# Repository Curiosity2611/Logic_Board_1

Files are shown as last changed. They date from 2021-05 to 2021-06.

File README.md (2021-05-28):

## Full Documentation

I will amend this documentation as the project progresses.

**Logic Board 1 Variants:**

- Logic Board 1A (No wireless)
	- LB1A_DCA7M4_R512MB_F4GB (Dual Core A7 + M4, 512MB DDR3L RAM, 4GB eMMC)
	- LB1A_SCA7M4_R512MB_F4GB (Single Core A7 + M4, 512MB DDR3L RAM, 4GB eMMC)
- Logic Board 1B (Only BLE 5.0)
	- LB1B_DCA7M4_R512MB_F4GB (Dual Core A7 + M4, 512MB DDR3L RAM, 4GB eMMC)
	- LB1B_SCA7M4_R512MB_F4GB (Single Core A7 + M4, 512MB DDR3L RAM, 4GB eMMC)
- Logic Board 1C (Only WiFi)
	- LB1B_DCA7M4_R512MB_F4GB (Dual Core A7 + M4, 512MB DDR3L RAM, 4GB eMMC)
	- LB1B_SCA7M4_R512MB_F4GB (Single Core A7 + M4, 512MB DDR3L RAM, 4GB eMMC)
- Logic Board 1D (WiFi + BLE 5.0)
	- LB1B_DCA7M4_R512MB_F4GB (Dual Core A7 + M4, 512MB DDR3L RAM, 4GB eMMC)
	- LB1B_SCA7M4_R512MB_F4GB (Single Core A7 + M4, 512MB DDR3L RAM, 4GB eMMC)

**Logic Board I/O:**

Common expansion Board for all Logic Board 1 Variants. 

## A little background about the project

How it all started.

### Problem

Recently I came accross the ST's line of Microprocessors and I felt it fascinating. I personally felt this is one of the best Microprocessor out there in the market as it is the combination of an MPU and an  MCU. This combination has many use cases and I felt I should try this out. So I bought STM32MP157C-DK2 development board and started experimenting! <br>

Previously I had little experience working on couple of popular linux dev boards like the BeagleBone Black
and the Raspberry Pi. They are both fantastic boards to work with and they both have good community support. But while working with them, I realised a few bunch of problems:

- **Raspberry Pi Compute Module 4 + IO Board**
    - CM4 is easy to use but not ideal for mass production.
    - No support for analog signals at hardware level.
    - Software PWM possible but not very precise.
    - Cannot support real time application or processing.
    - Not fully open-source and very minimum customization possible. <br>
<br>

- **BeagleBone Black**
    - Easy to use but user has to own build hardware for production.
    - PRUs make RT applications possible but super difficult to use.
    - Cannot support MIPI-DSI and HD graphics.
    - Programming PRUs is not an easy task.

### Solution

**Best of both worlds**

**Hello World STM32MP1 !!**

- Board design inspired from Raspberry Pi Compute Module 4 and CM4 IO board.
- Operating system derived from Beaglebone Black with implementation of Bonescript Library and Cloud9 IDE.
- Footprint compatible Single or dual Cortex-A7 Processors + dedicated Cortex-M4 core for real-time and low-power applications.
- Support for MIPI-DSI display for HMI applications.
- Fully open-source Hardware and Software.

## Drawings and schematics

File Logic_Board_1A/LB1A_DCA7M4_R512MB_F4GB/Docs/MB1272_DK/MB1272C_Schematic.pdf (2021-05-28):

Title: MB1272

Size:

Reference:
A4 | Sheet: | of

Revision:

Project: STM32MP15-DISCO

C 01 | MB1272
12-SEP-18

DK2

Date:

Variant:

Table of contents | Legend

New in Rev C : X6 OSC, 100nF->1uF on C147 to C161, C191/C192 added, X1 NDK reference, ANA0/1 -> ARD_A2/3

Text to be added to silkscreen.

Sheet 1: Project (this page)

Sheet 2: Top

# STM32MP15-DISCO

MB1272

Sheet 3: STM32 MPU I/Os

Sheet 4: Power MPU

Sheet 7: Audio

Sheet 9: HDMI

Sheet 6: USB Host Hub &TypeC DRP

Sheet 5: Power PMIC

Sheet 8: DSI LCD Connector

Warning text.

Sheet 10: GPIO & Arduino Connectors

Sheet 11: DDR3 16bits

U_MB1272-TOP
MB1272-TOP.SchDoc

# Open Platform License Agreement

The Open Platform License Agreement (“Agreement”) is a binding legal contract between you ("You")

and STMicroelectronics International N.V. (“ST”), a company incorporated under the laws of the

Netherlands acting for the purpose of this Agreement through its Swiss branch 39, Chemin du

Champ des Filles, 1228 Plan-les-Ouates, Geneva, Switzerland.

By using the enclosed reference designs, schematics, PC board layouts, and documentation, in hardcopy

or CAD tool file format (collectively, the “Reference Material”), You are agreeing to be bound by

the terms and conditions of this Agreement. Do not use the Reference Material until You have read

and agreed to this Agreement terms and conditions. The use of the Reference Material automatically

implies the acceptance of the Agreement terms and conditions.

The complete Open Platform License Agreement can be found on www.st.com/opla.

Sheet 10: Ethernet

Sheet 11: Peripherals

Sheet 10: WLAN Bluetooth

Sheet 11: Peripherals

Notes to generate the
board layout.

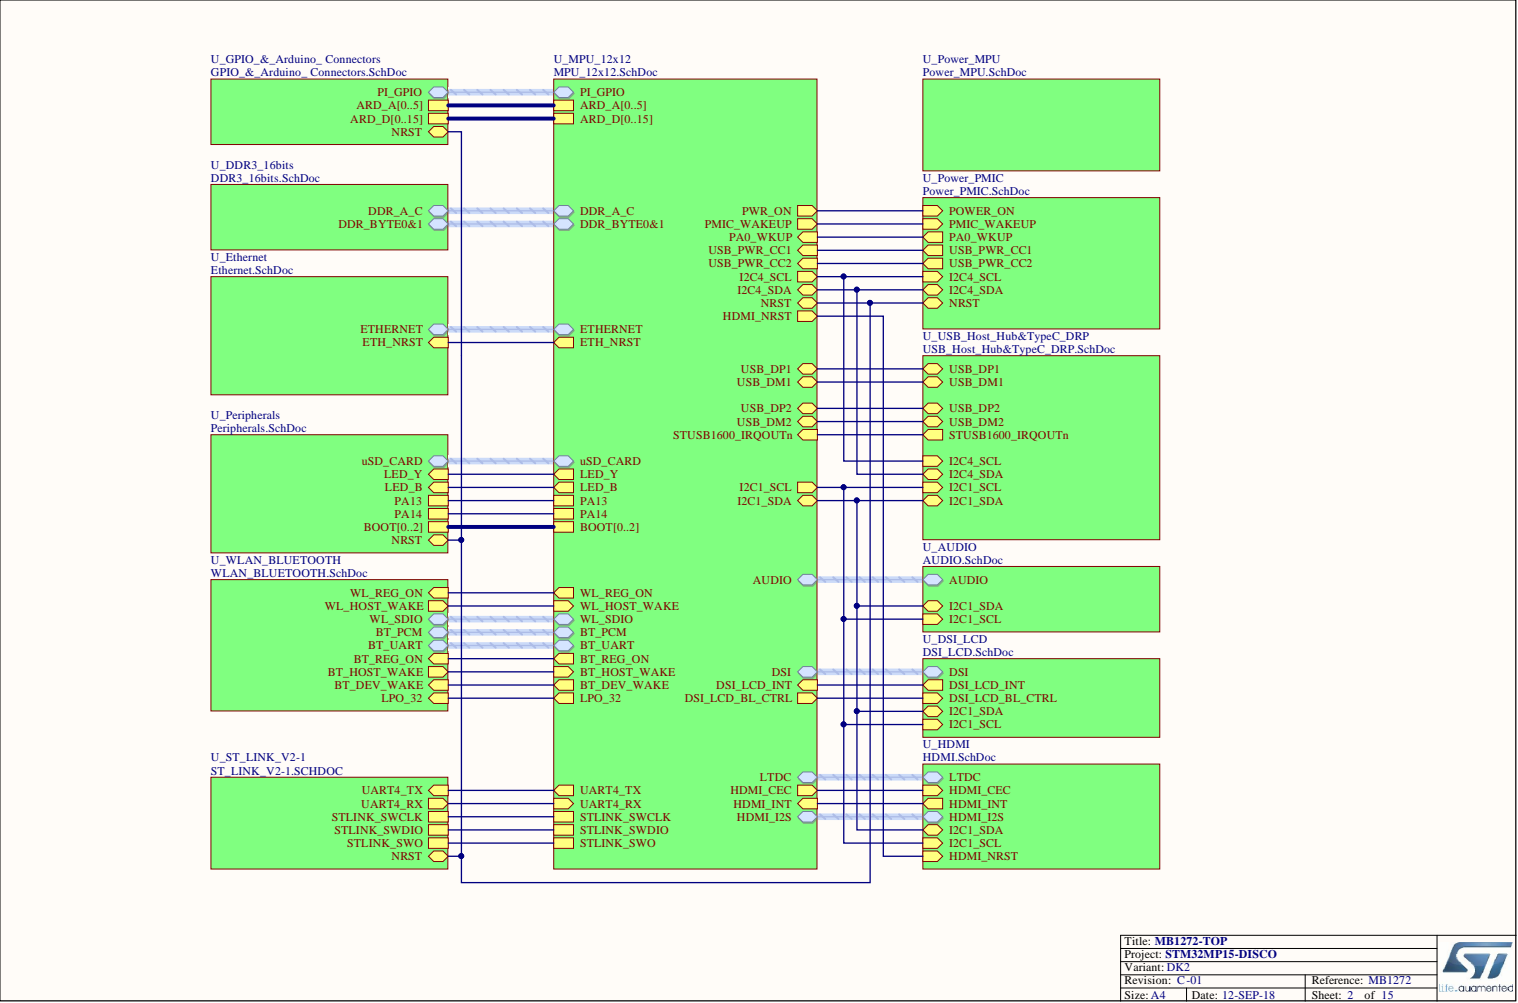
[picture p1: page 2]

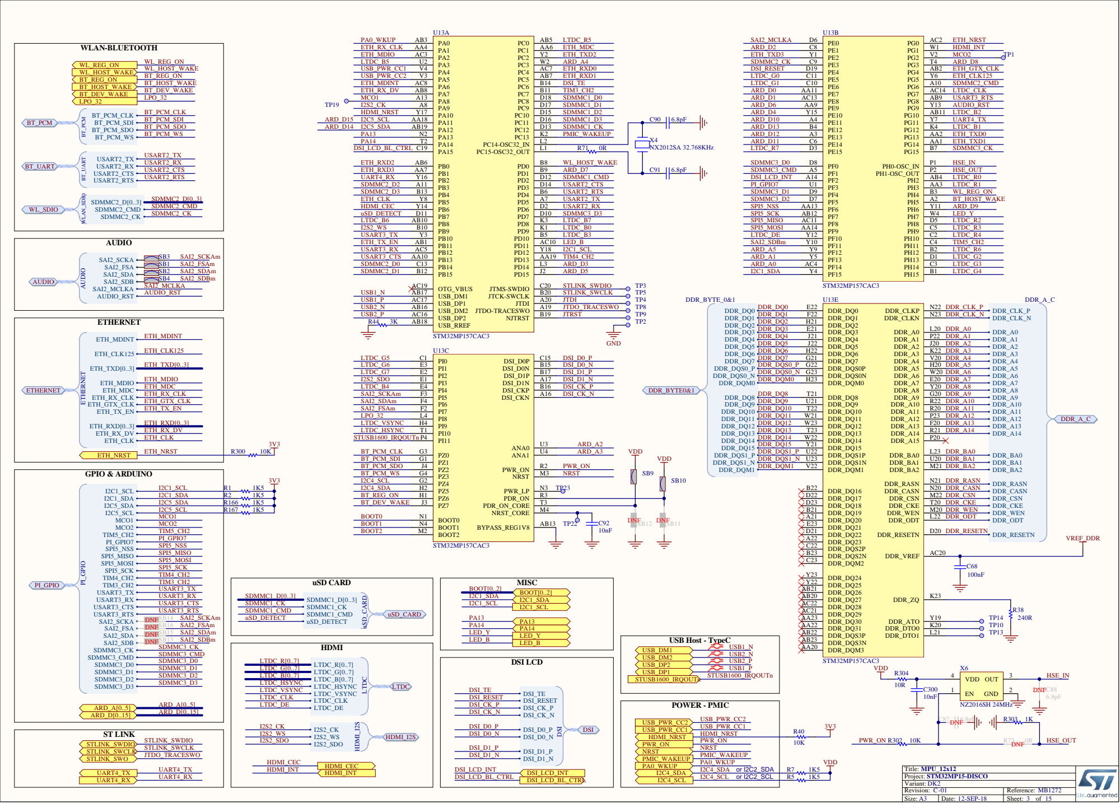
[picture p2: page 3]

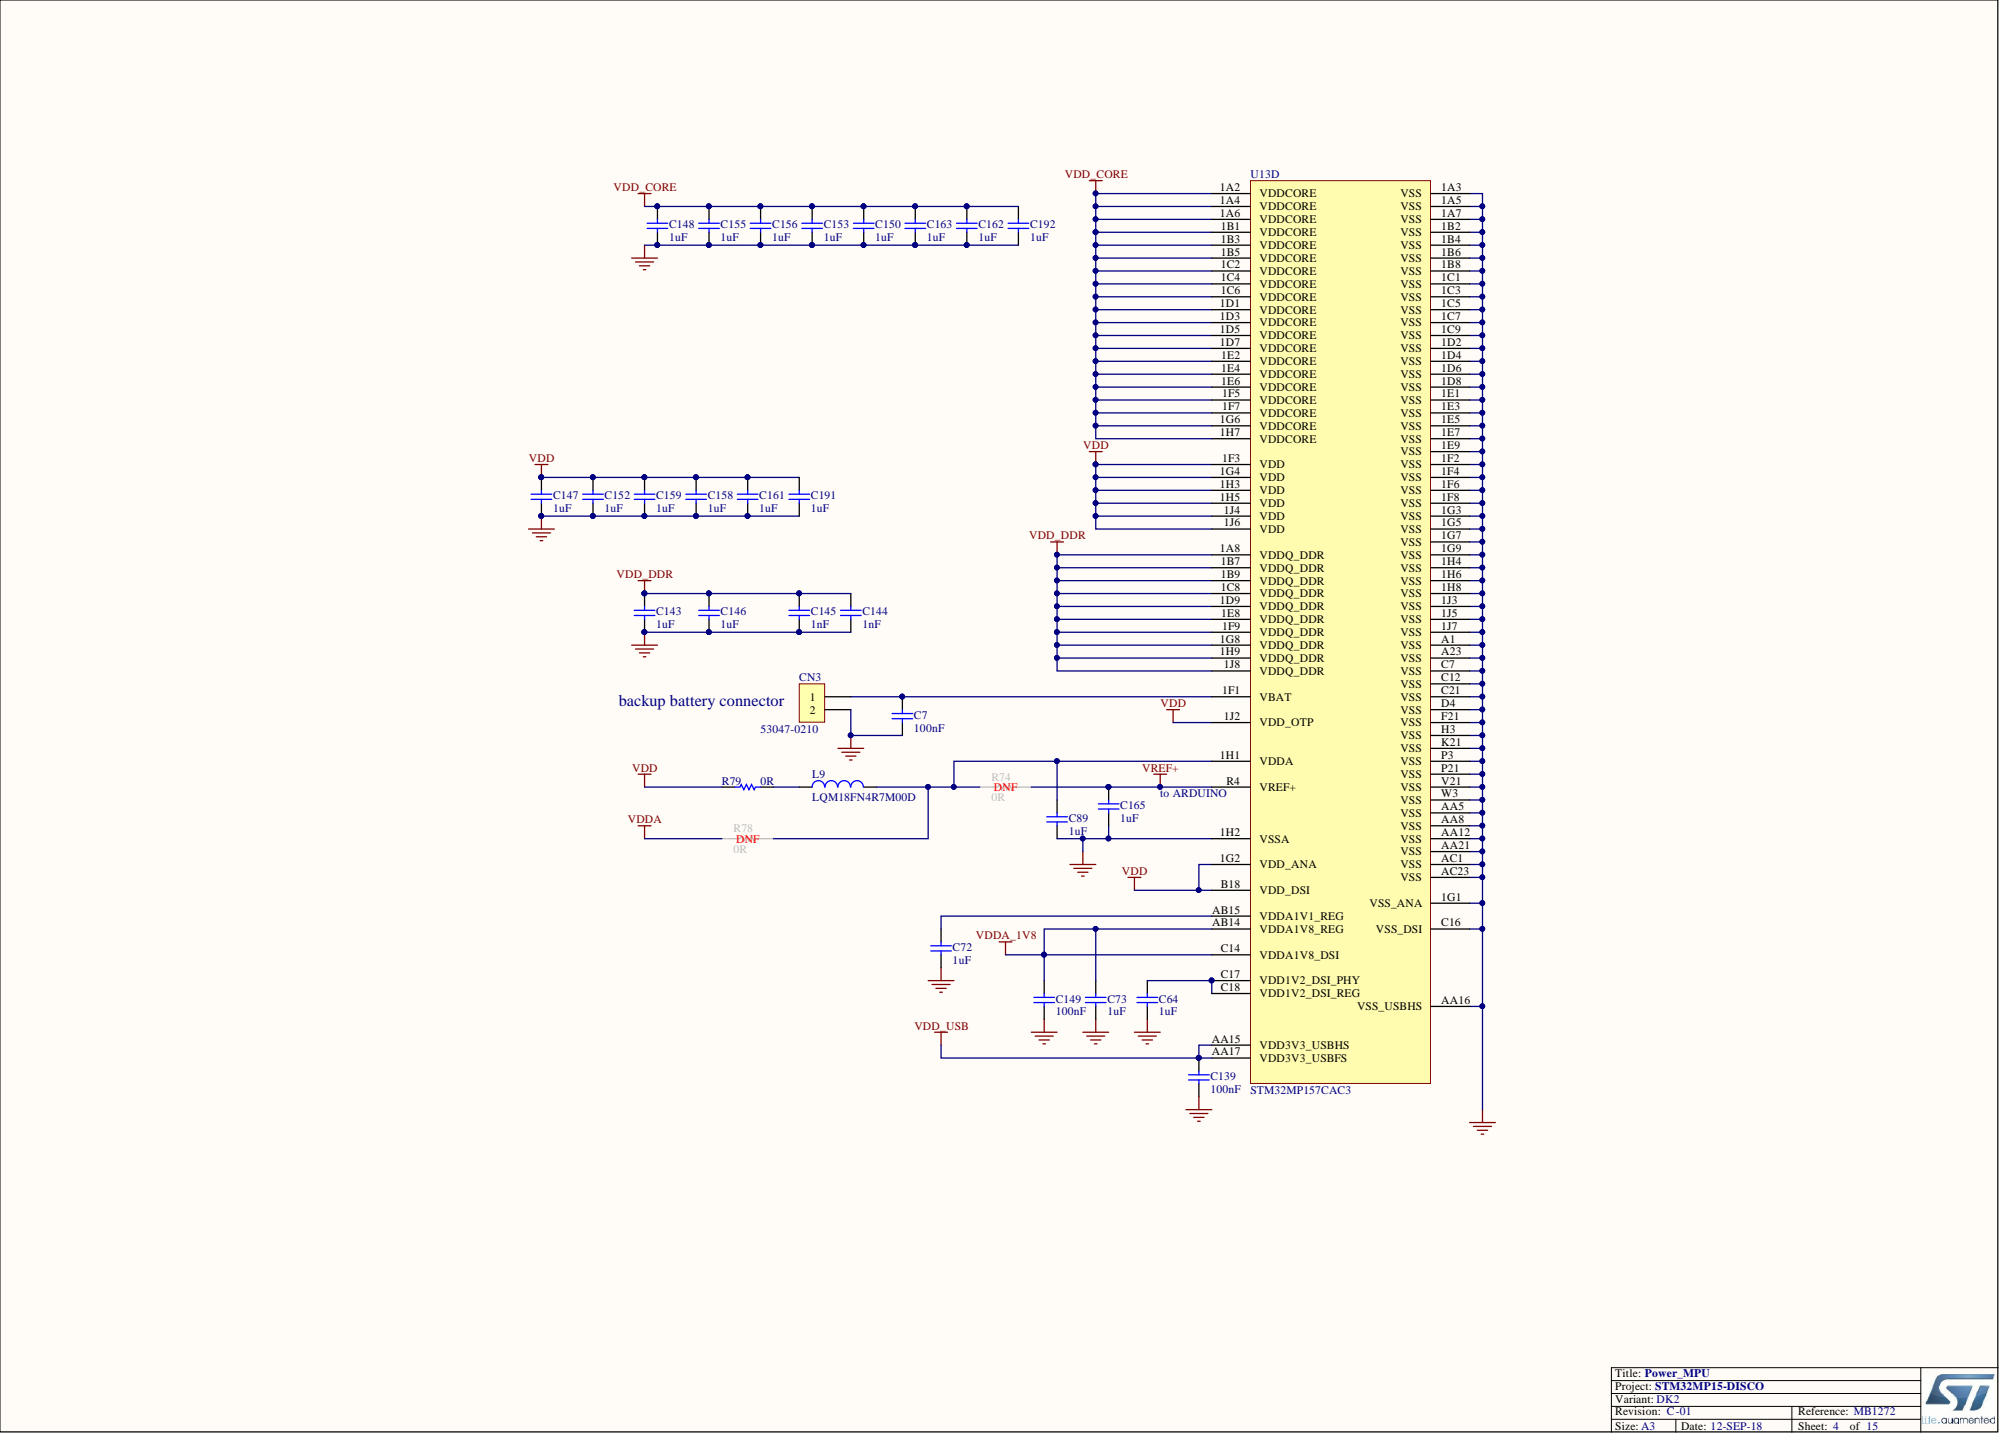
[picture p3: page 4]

R74 DNF | VREF+

VSSA 1H2

VDD_DSI B18

VDDA1V8_REG AB14 VDDA1V1_REG AB15

VDDA1V8_DSI C14

VDD1V2_DSI_PHY C17
VDD1V2_DSI_REG C18

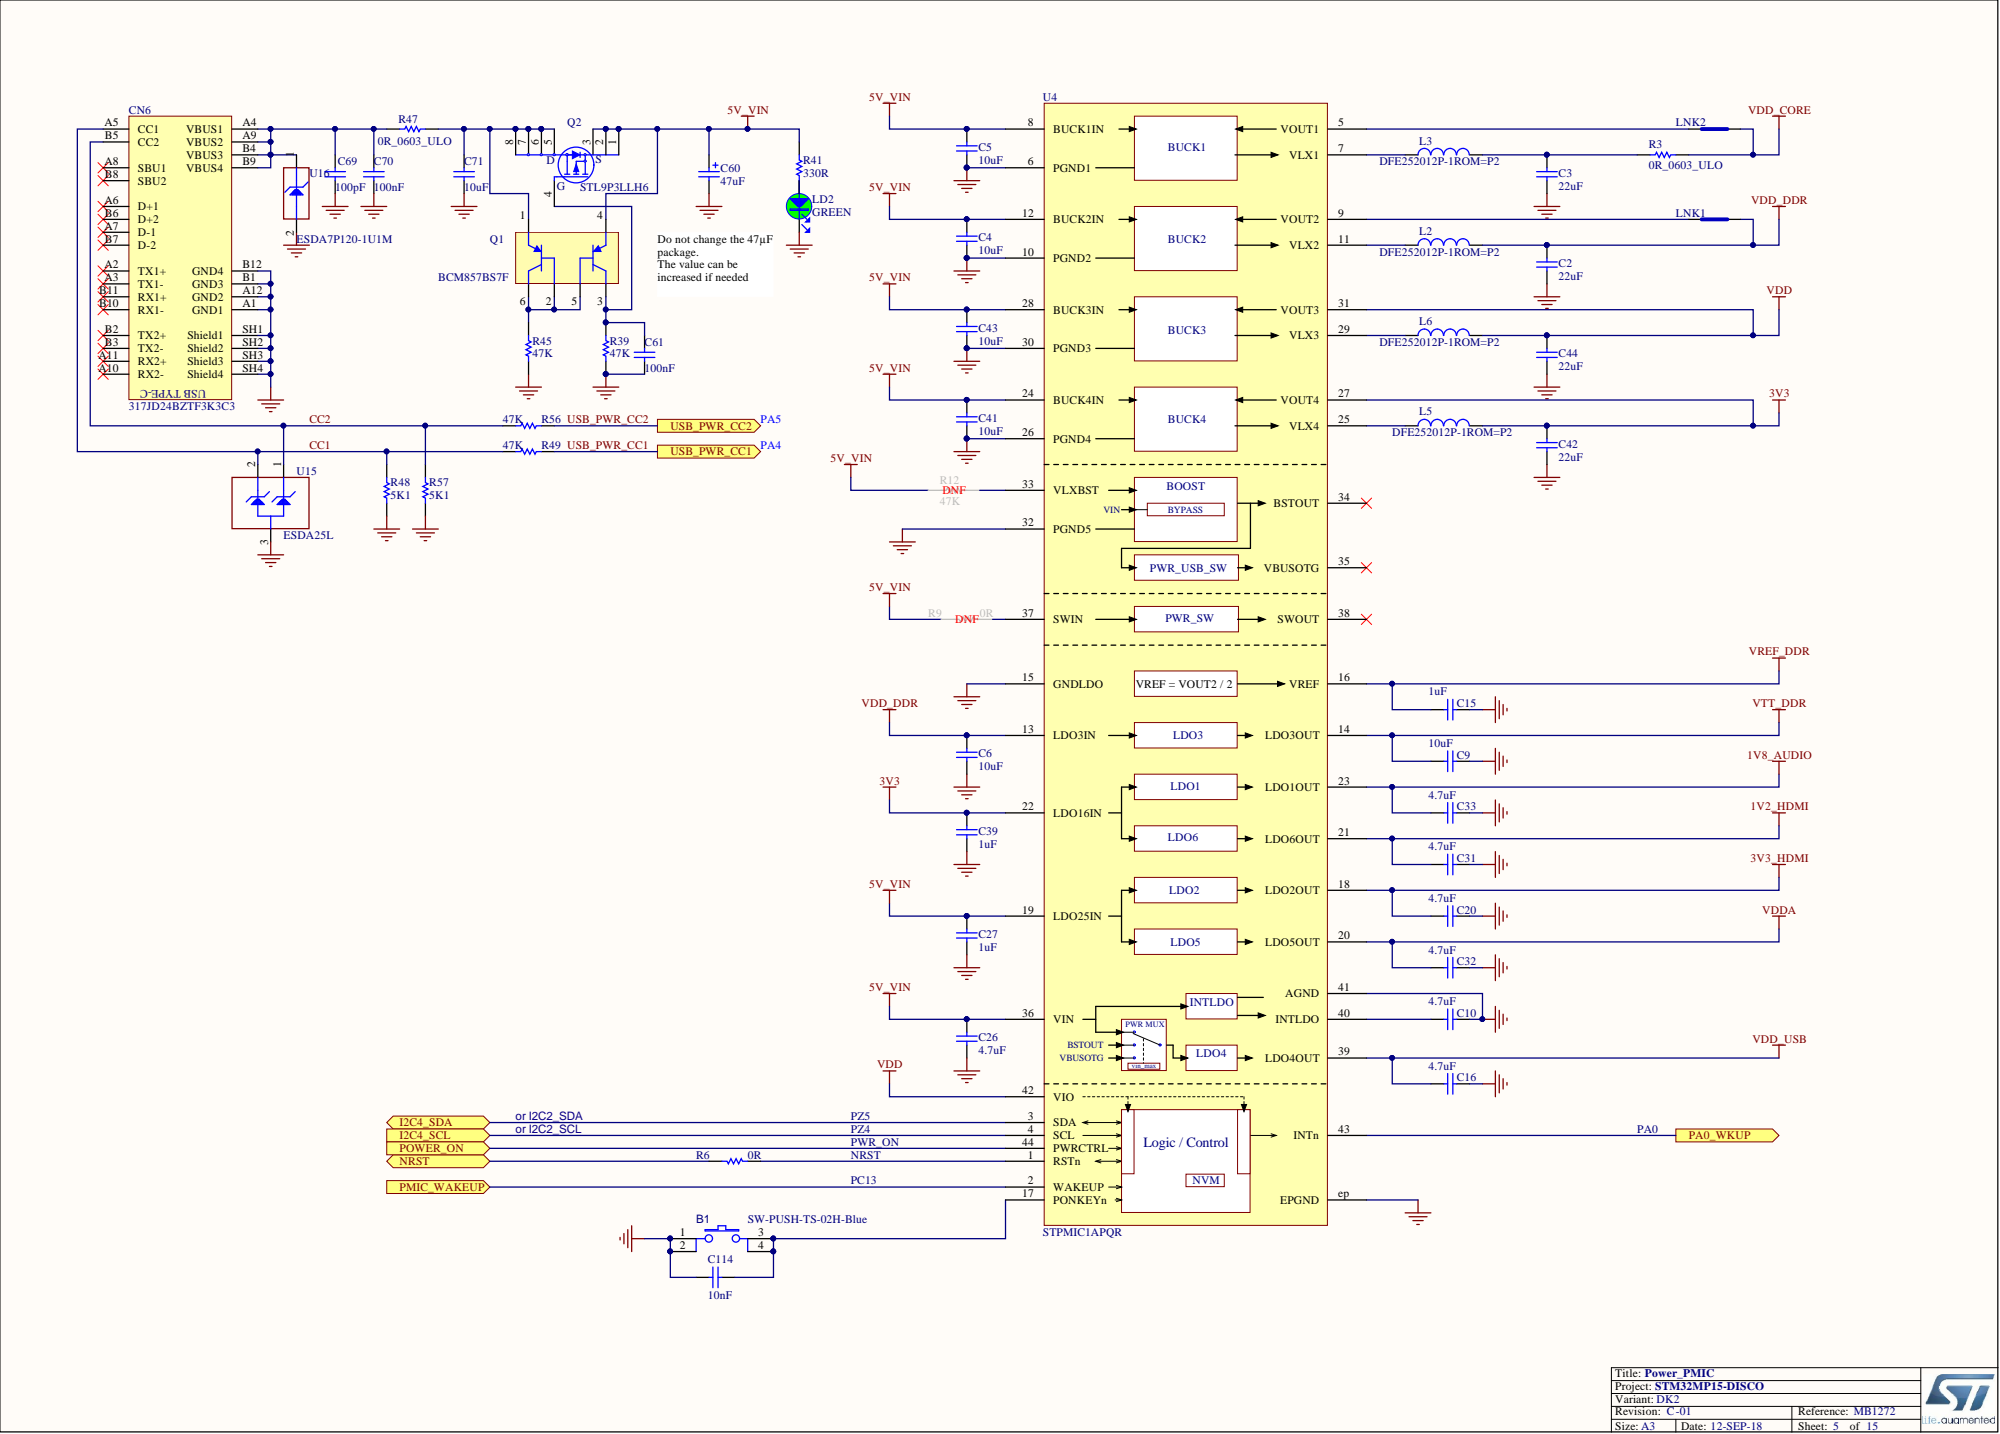
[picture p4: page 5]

package. The value can be increased if needed

PWR MU vin_max | X

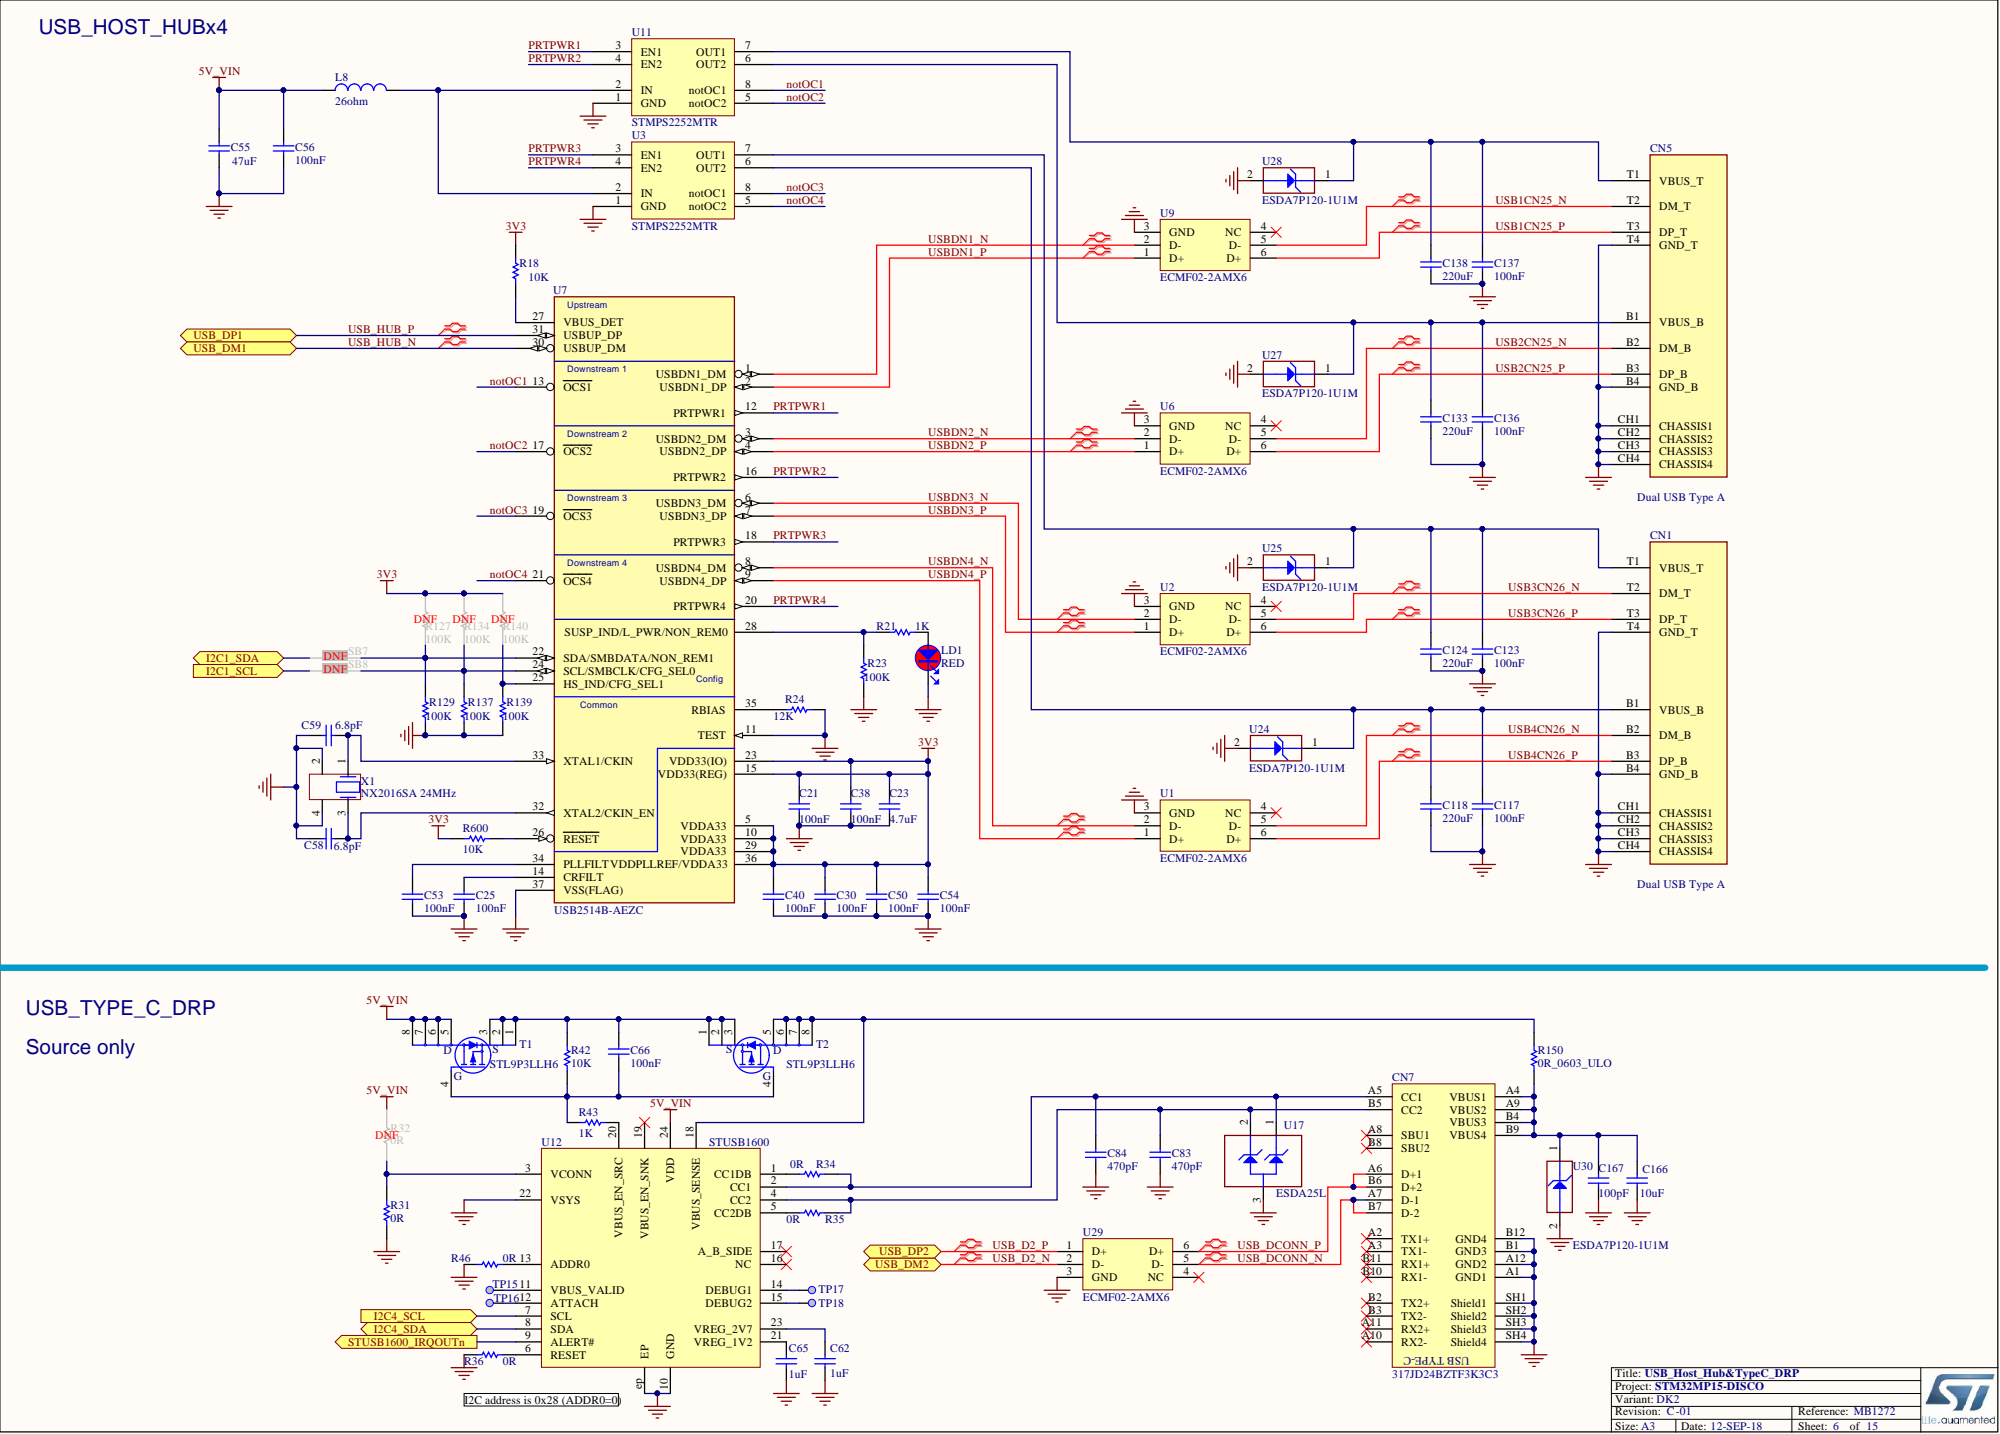
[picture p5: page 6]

USB1CN25_P | DP_T T3

GND_T T4

USB2CN25_P | DP_B B3

C133 | C136 | GND_B B4

CHASSIS4 CH4

CRFILT 14

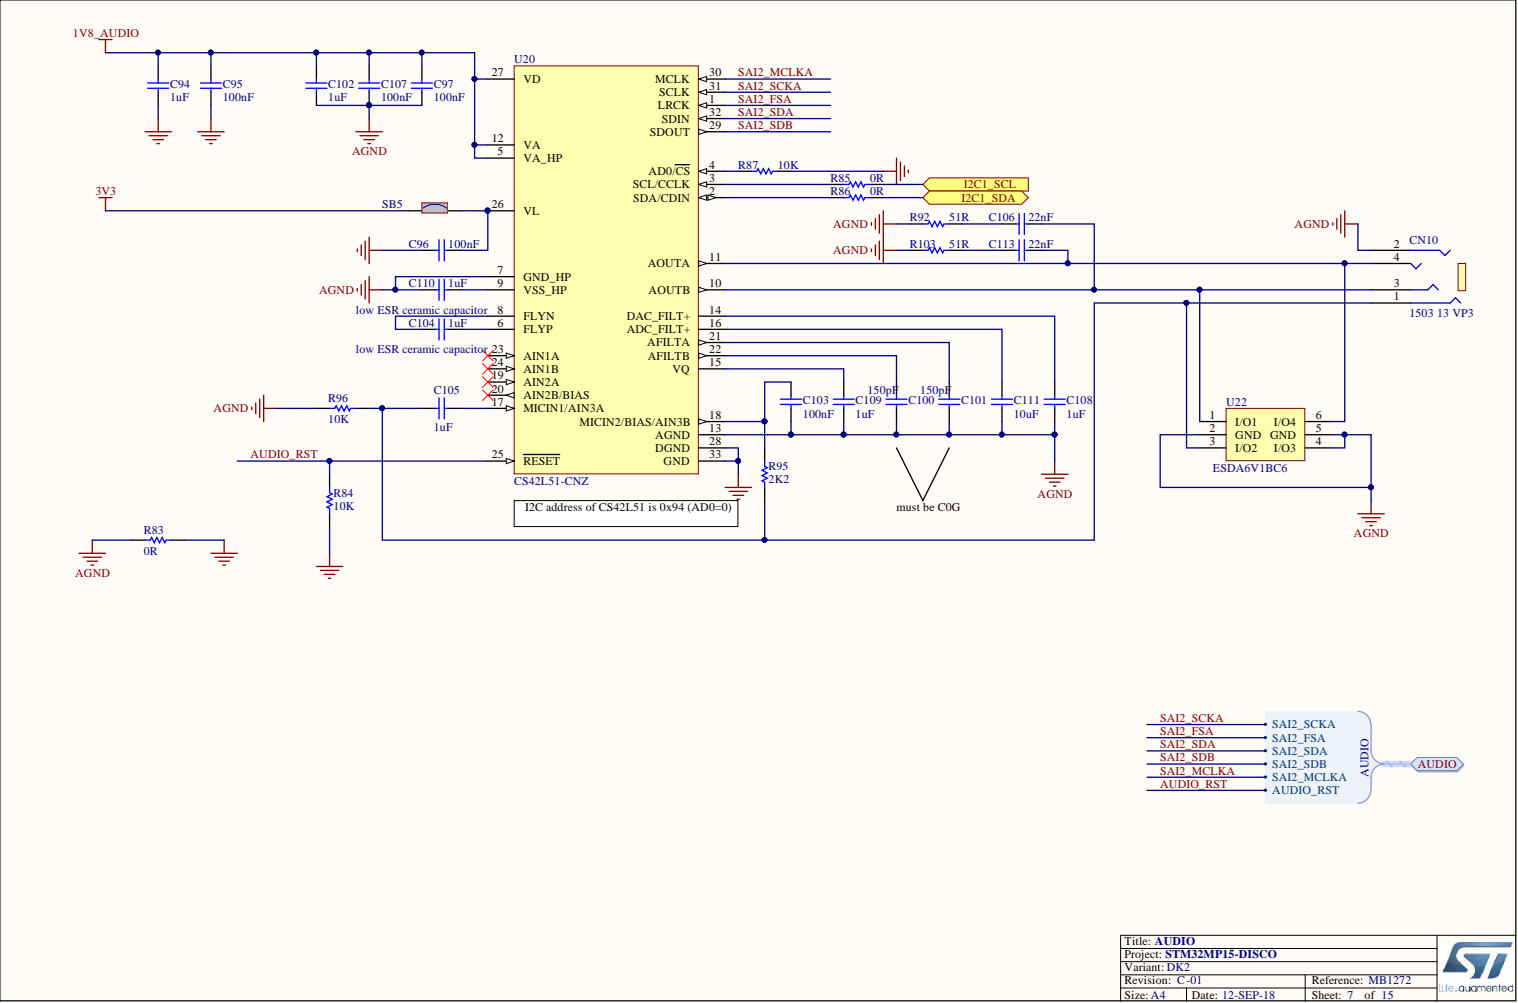
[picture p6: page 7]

GND_HP 7

low ESR ceramic capacitor

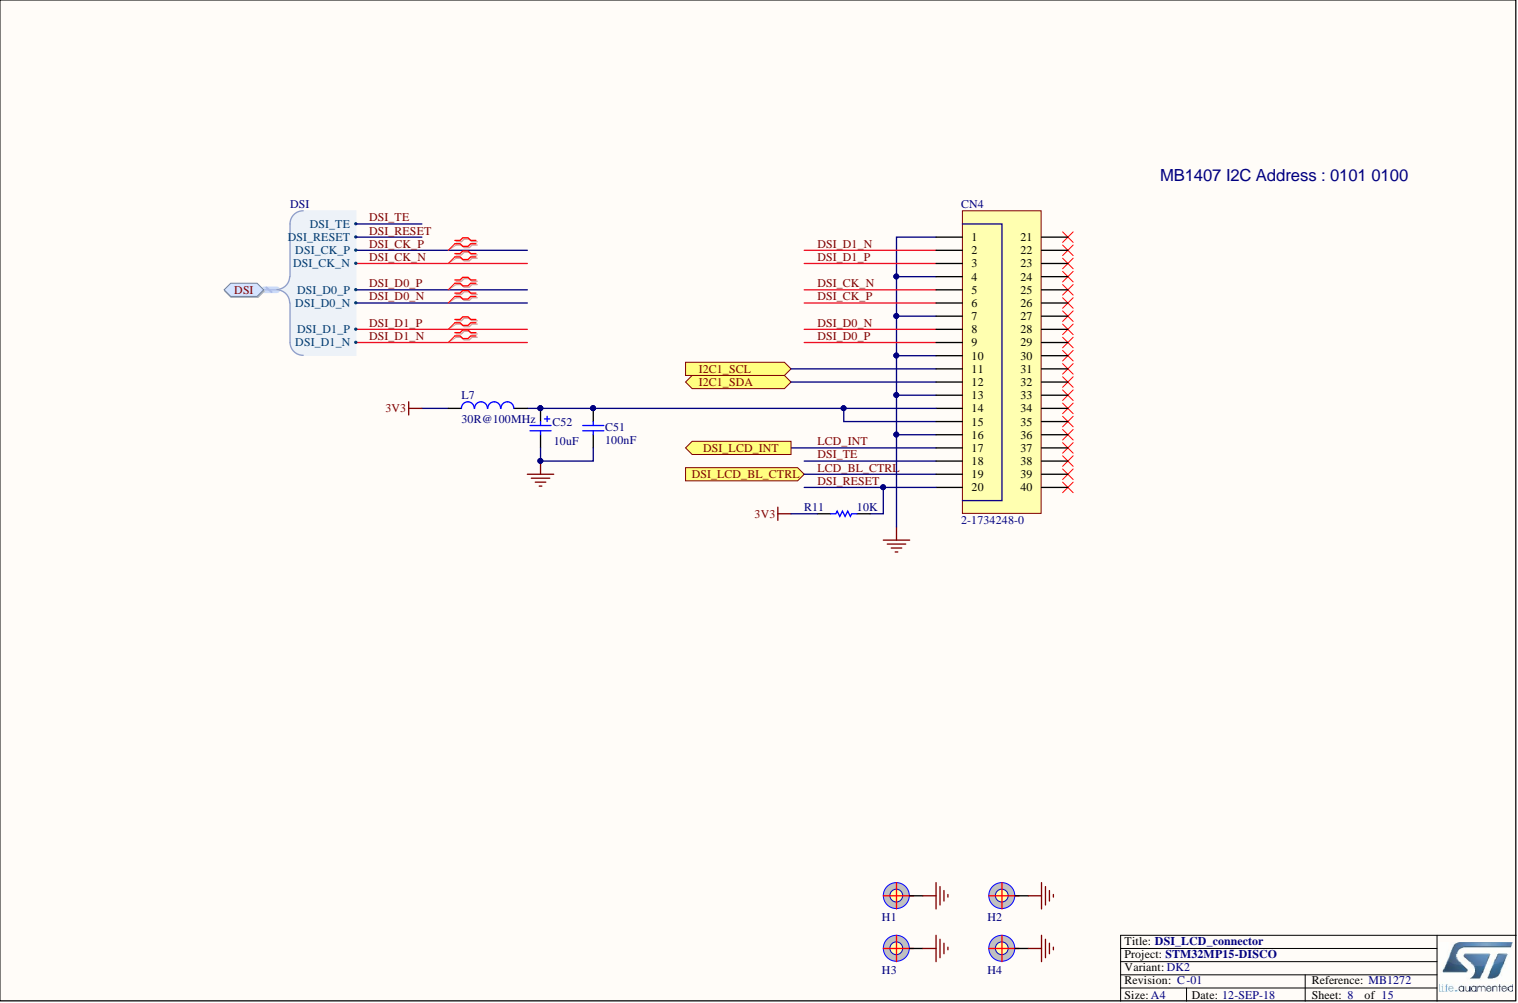
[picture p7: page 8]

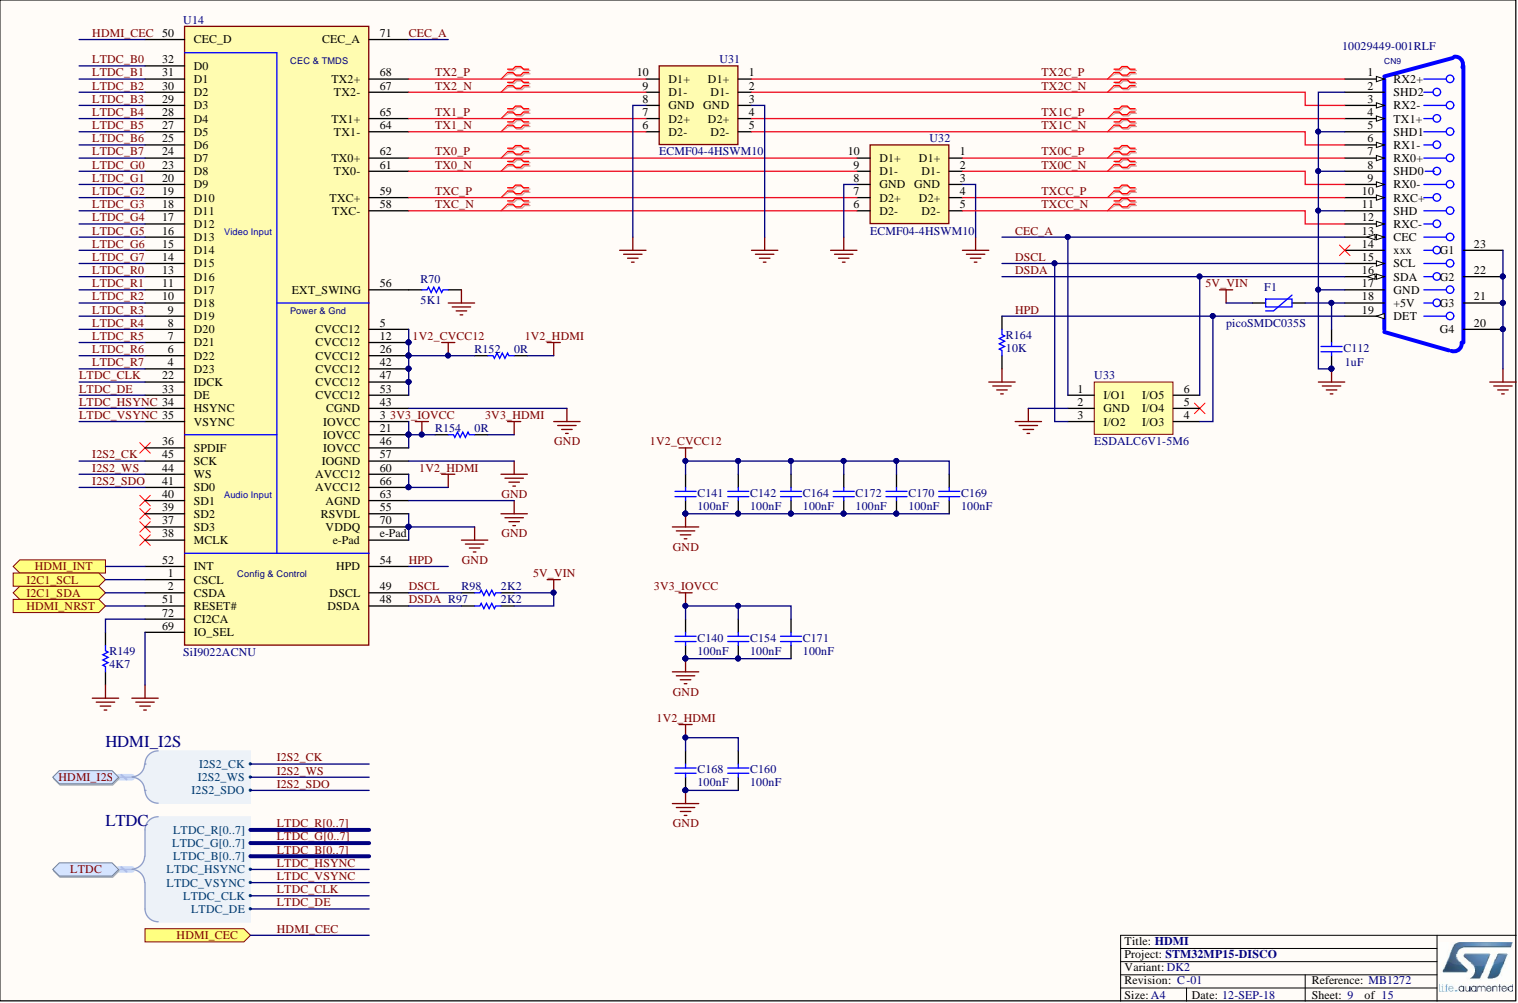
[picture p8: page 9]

GND 8

TX1_N | D2- 6 | TX1C_N
TX0_P | | U32

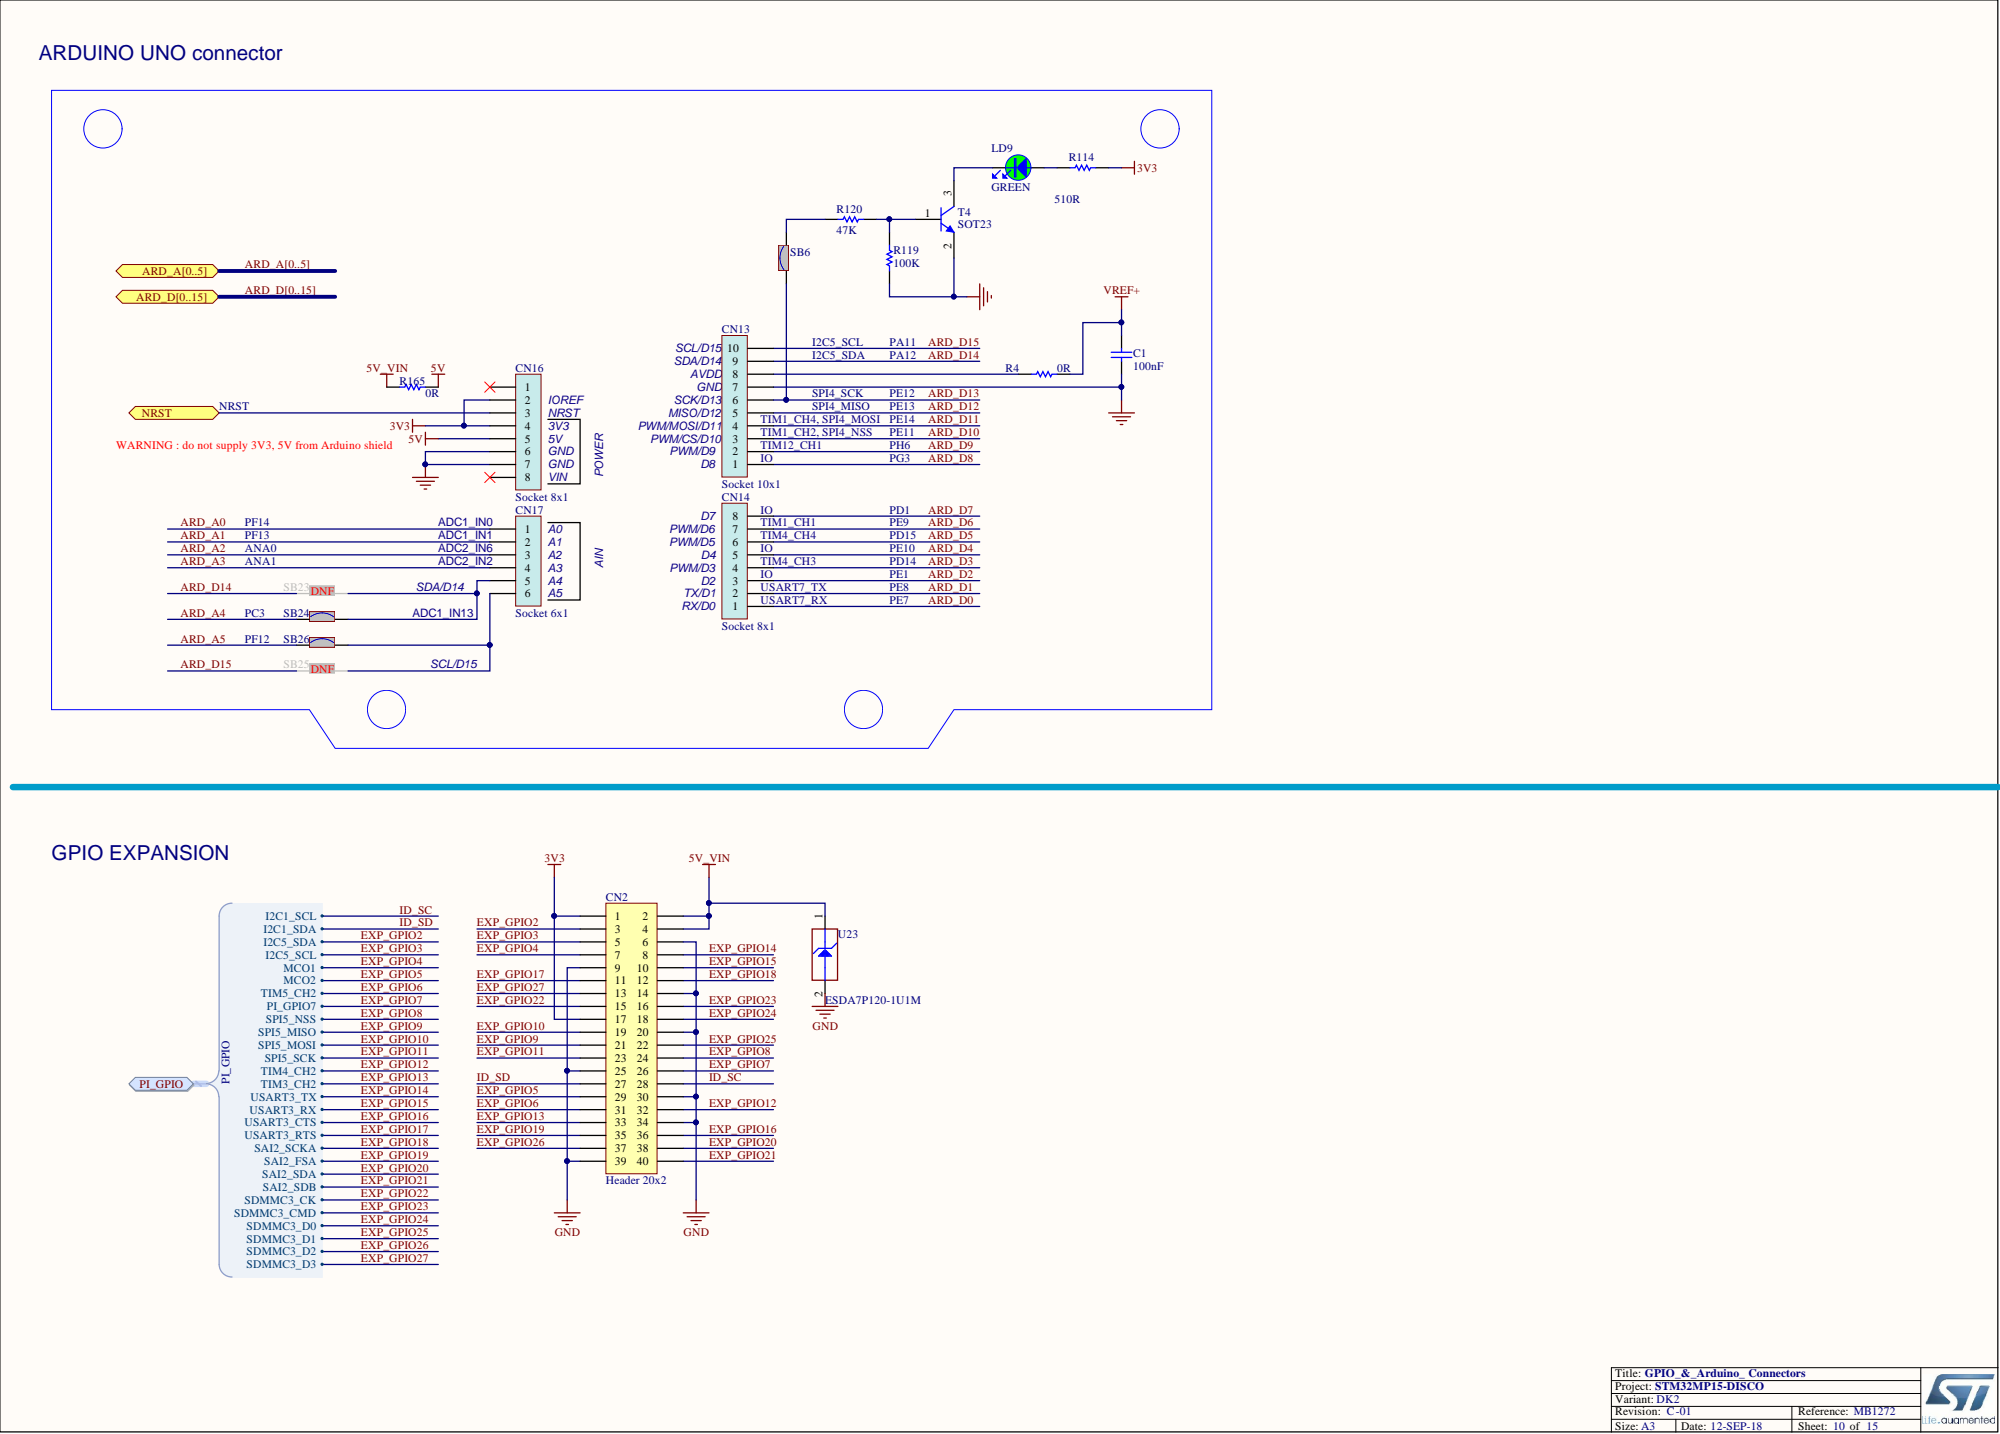
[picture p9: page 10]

5V WARNING : do not supply 3V3, 5V from Arduino shield

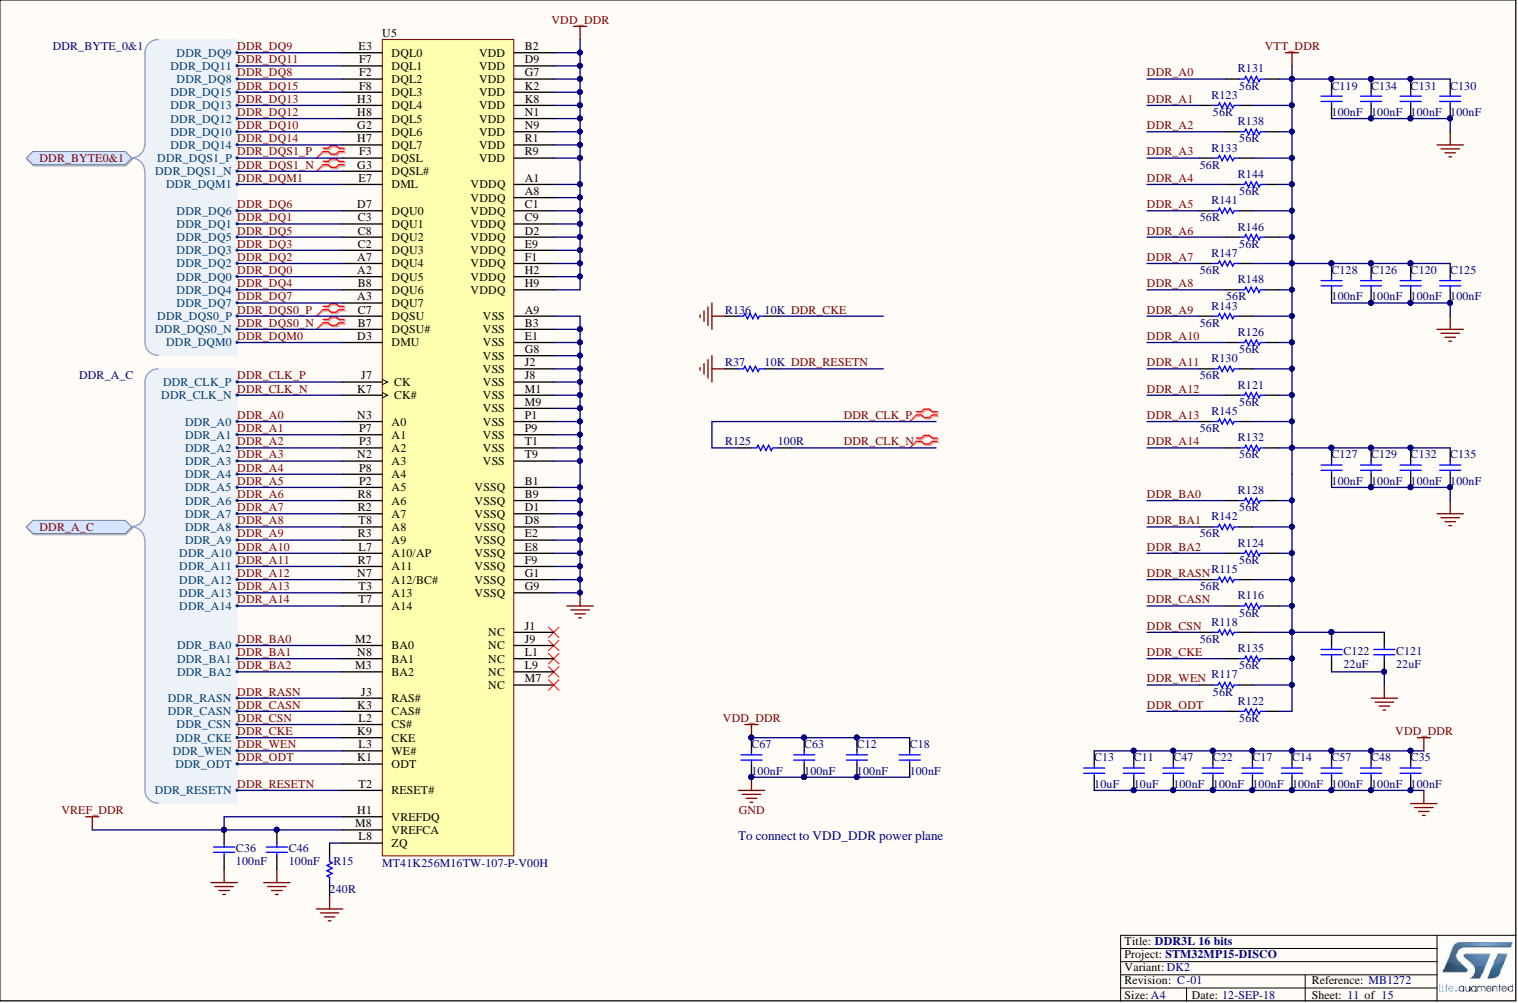
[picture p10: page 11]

D 9
G 7
K 2

N 1
N 9

A 1
A 8

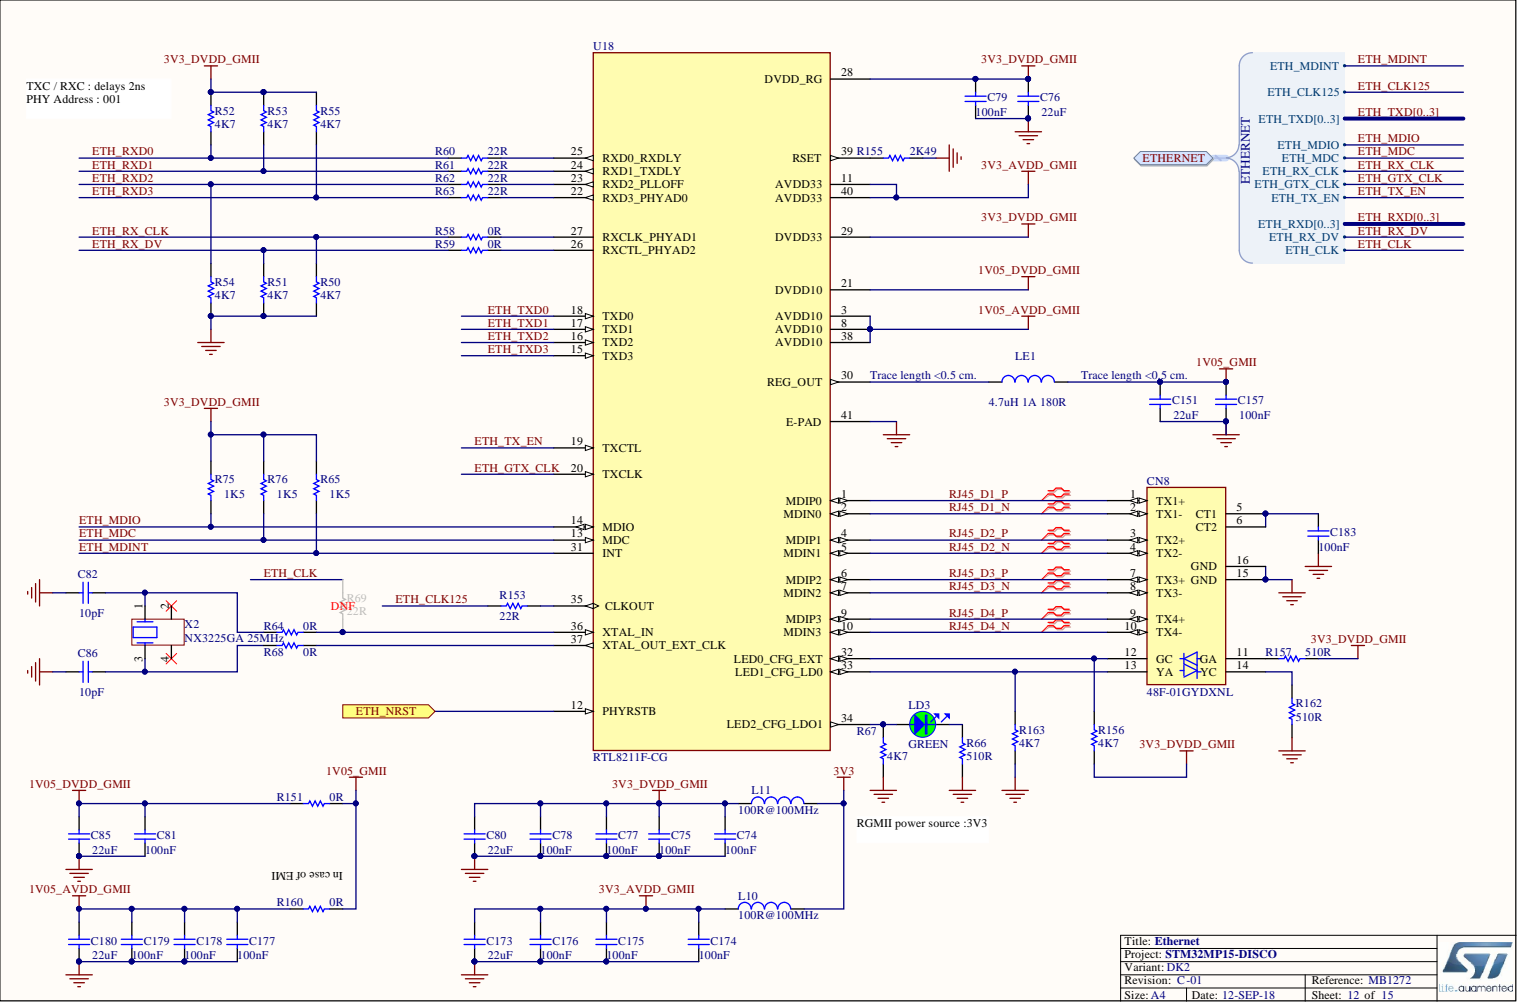
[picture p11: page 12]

ETH_MDC | | | MDC 13

INT 31 | RJ45_D2_N

CLKOUT 35 XTAL_OUT_EXT_CLK 37 XTAL_IN 36 PHYRSTB 12 | RJ45_D3_P | TX3- 8 TX3+ 7

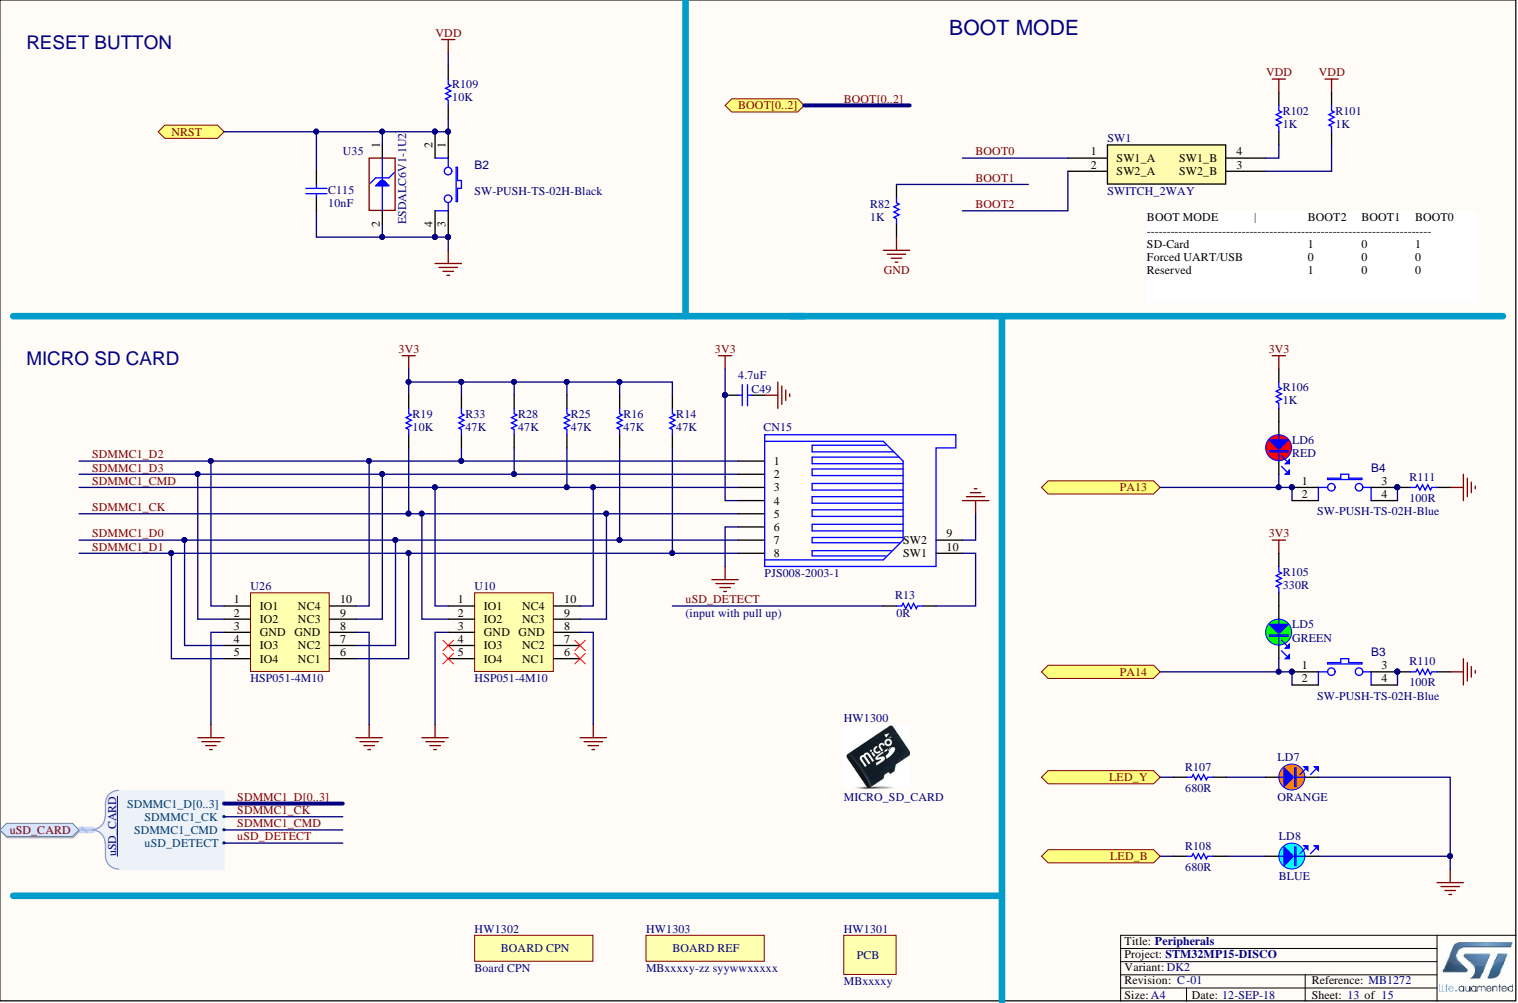
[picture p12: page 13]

SW-PUSH-TS-02H-Black

SW-PUSH-TS-02H-Blue

uSD_DETECT
(input with pull up)


GND 43 GND 44 GND 45 GND 46


Title: ST-LINK/V2-1 with support of SWD only

Must be on a border of the PCB.

ESD PROTECTION SHOULD BE CLOSE TO THE CONNECTOR

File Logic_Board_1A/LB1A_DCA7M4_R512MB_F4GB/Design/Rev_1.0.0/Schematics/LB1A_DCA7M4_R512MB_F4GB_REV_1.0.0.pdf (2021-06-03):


Table of Contents
1. Logic Board 1A Block Diagram (This Page)
2. STM32MP157CAC3 MPU
3. Board to Board Connectors
4. Power Management IC
5. 4GB eMMC Storage
6. 512MB DDR3L SDRAM

BLOCK DIAGRAM
File: STM32MP157CAC3_MPU.sch Sheet: Board to Board Connectors File: Board to Board Connectors.sch Sheet: STPMIC

Design Notes
1. Wireless Connectivity is removed for the sake
of simplicity and testing purposes.
2. Seperate development boards are made for
Wireless to test on STM31MP157C-DK2.
Important Note:
Always match the compatible revision numbers carfully.
PCB Revision number - 1.0.0
BOM Revision number - 1.0.0
Assembly docs Rev number - 1.0.0
Fabrication file Rev number - 1.0.0

File: eMMC.sch Sheet: DDR3L_RAM
DDR3L
File: DDR3L_RAM.sch LOGIC BOARD 1A TOP PAGE

File: LB1A_DCA7M4_R512MB_F4GB.sch Sheet: /
Id: 1/6 Title: LOGIC BOARD 1A (LB1A_DCA7M4_R512MB_F4GB)


Sheet: /STM32MP157CAC3_MPU/
File: STM32MP157CAC3_MPU.sch
Id: 2/6 Title: LOGIC BOARD 1A (LB1A_DCA7M4_R512MB_F4GB)

1. Used for PMIC & USB-C


Id: 3/6 Title: LOGIC BOARD 1A (LB1A_DCA7M4_R512MB_F4GB) File: Board to Board Connectors.sch Sheet: /Board to Board Connectors/


PMIC Power On Sequence: To MPU

1. Default = 1.2V; Imax = 2000mA; Application = CORE
2. Default = 1.1V; Imax = 1600mA; NOT ON BY DEFAULT; Application = DDR3L RAM
3. Default = 1.8V; Imax = 1000mA; Application = VIO

5. Default = 1.8V; Imax = 800mA; NOT ON BY DEFAULT; Application = GP
6. Default = 2.9V; Imax = 800mA; Application = SD-Card or GP
7. Default = 1.8V; Imax = 150mA; NOT ON BY DEFAULT; Application = DDR3 Termination
8. Default (fixed) = 3.3V; Imax = 200mA; Application = USB PHY
9. Default = 2.9V; Imax = 800mA; Application = Flash Memory or GP
10. Default = 1.0V; Imax = 350mA; NOT ON BY DEFAULT; Application = GP



Connect to RAM VDD power plane

Sheet: /DDR3L_RAM/
File: DDR3L_RAM.sch
Id: 6/6 Title: LOGIC BOARD 1A (LB1A_DCA7M4_R512MB_F4GB)

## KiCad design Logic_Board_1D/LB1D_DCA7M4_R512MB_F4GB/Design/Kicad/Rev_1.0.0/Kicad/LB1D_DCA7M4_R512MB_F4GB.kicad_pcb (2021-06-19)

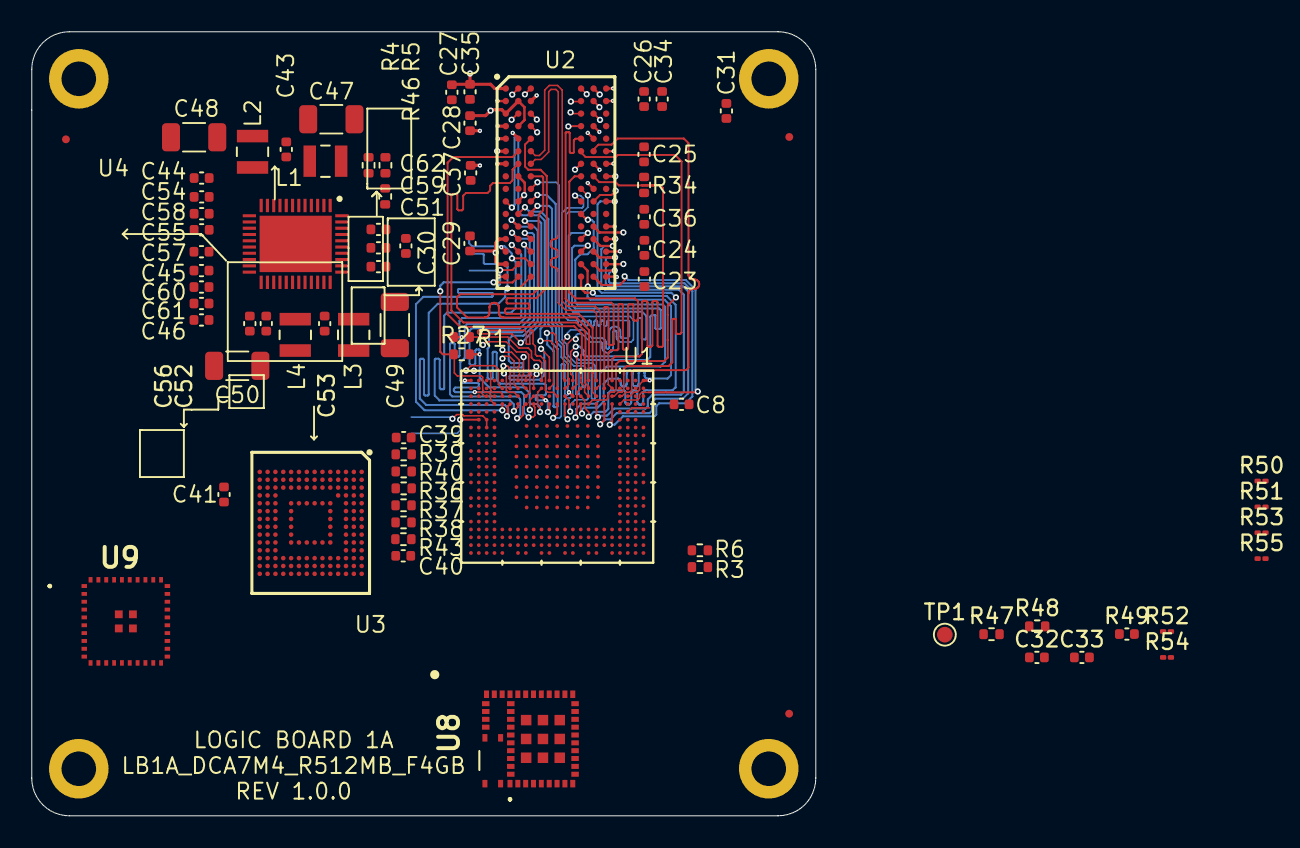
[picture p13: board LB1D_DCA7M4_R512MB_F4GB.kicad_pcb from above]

Board: 4 copper layers, 50.0 x 50.0 mm, 157 parts (0 on the bottom side), 213 nets.

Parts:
C1, C2, C5, C6, C51, C52, C63, C64, C65, C66, C67, C68, C69, C70, C72, C73, C74: 1uF; C_0402_1005Metric
C3, C4, C8, C9, C10, C11, C12, C13, C14, C15, C16, C17, C18, C19, C20, C23, C24, C25, C26, C27, C28, C29, C30, C31, C36, C37, C38, C39, C40: 100nF; C_0402_1005Metric
C7: 10nF; C_0402_1005Metric
C21, C22, C32, C34, C35, C41, C43, C44, C45, C46, C54: 10uF; C_0402_1005Metric
C33, C75, C76, C77: 10pF; C_0402_1005Metric
C42: 2.2uF; C_0402_1005Metric
C47, C48, C49, C50: 22uF; C_1206_3216Metric
C53, C55, C56, C57, C58, C59, C60, C61, C62: 4.7uF; C_0402_1005Metric
FID1, FID2, FID3, FID4, FID5, FID6: Fiducial; Fiducial_0.5mm_Mask1.5mm
H1, H2, H3, H4: MountingHole_Pad; MountingHole_2.2mm_M2_DIN965_Pad
L1, L2, L3, L4: 1uH; MGV2520101R0M-10
R1, R34: 240E; R_0402_1005Metric
R2, R3, R4, R5: 1k5; R_0402_1005Metric
R6, R27, R35, R46: 10k; R_0402_1005Metric
R7: 3k; R_0402_1005Metric
R8, R9, R10, R11, R12, R13, R14, R15, R16, R17, R18, R19, R20, R21, R22, R23, R24, R25, R28, R29, R30, R31, R32, R33: 56E; R_0402_1005Metric
R26, R47, R48: 100E; R_0402_1005Metric
R36, R37, R38, R39, R40, R41, R42, R43, R44, R45: 47k; R_0402_1005Metric
R49: 0E; C_0402_1005Metric
R50, R51, R52, R53, R54, R55: 100k; C_01005_0402Metric
TP1: TestPoint; TestPoint_Pad_D1.0mm
U1: STM32MP157CAC3
U2: AS4C256M16D3LC-12BCN
U3: S40FC004C1B2C00000
U4: STPMIC1BPQR
U5, U6, U7: DF40C-70DP-0.4V(51); DF40C70DP04V51
U8: WFM200S022XNA3R; WFM200S022XNA3
U9: BGX220S22HNA21R; BGX220S22HNA21
X1: 32.768kHz; SiT1533AC-H5-DCC-32.768E
X2: 24MHz; TSX3225240000MF10ZC3

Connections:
5V_VIN: C43.1, C44.1, C45.1, C46.1, C51.1, C52.1, C53.1, U4.8, U4.12, U4.19, U4.22, U4.24, U4.28, U4.36, U6.2, U6.4, U6.6, U6.8, U6.10
ANA0: U1.U3, U7.31
ANA1: U1.U4, U7.33
BLE_RESET: U1.Y5, U9.35
BOOT0: U1.N1, U5.37
BOOT1: U1.N4, U5.25
BOOT2: U1.M2, U5.41
DDR_A0: R8.2, U1.L20, U2.N3
DDR_A1: R9.2, U1.P22, U2.P7
DDR_A2: R10.2, U1.J20, U2.P3
DDR_A3: R11.2, U1.K22, U2.N2
DDR_A4: R12.2, U1.V20, U2.P8
DDR_A5: R13.2, U1.H20, U2.P2
DDR_A6: R14.2, U1.W20, U2.R8
DDR_A7: R15.2, U1.E20, U2.R2
DDR_A8: R16.2, U1.Y20, U2.T8
DDR_A9: R17.2, U1.G20, U2.R3
DDR_A10: R18.2, U1.R22, U2.L7
DDR_A11: R19.2, U1.R20, U2.R7
DDR_A12: R20.2, U1.P23, U2.N7
DDR_A13: R21.2, U1.F20, U2.T3
DDR_A14: R22.2, U1.R21, U2.T7
DDR_BA0: R23.2, U1.L23, U2.M2
DDR_BA1: R24.2, U1.U20, U2.N8
DDR_BA2: R25.2, U1.M21, U2.M3
DDR_CASN: R33.2, U1.N20, U2.K3
DDR_CKE: R28.1, R35.2, U1.T20, U2.K9
DDR_CLK_N: R26.1, U1.N23, U2.K7
DDR_CLK_P: R26.2, U1.N22, U2.J7
DDR_CSN: R30.1, U1.M22, U2.L2
DDR_DQ0: U1.E22, U2.A2
DDR_DQ1: U1.F22, U2.C3
DDR_DQ2: U1.H21, U2.A7
DDR_DQ3: U1.E21, U2.C2
DDR_DQ4: U1.J21, U2.B8
DDR_DQ5: U1.J22, U2.C8
DDR_DQ6: U1.H22, U2.D7
DDR_DQ7: U1.G21, U2.A3
DDR_DQ8: U1.T21, U2.F2
DDR_DQ9: U1.U21, U2.E3
DDR_DQ10: U1.T22, U2.G2
DDR_DQ11: U1.W21, U2.F7
DDR_DQ12: U1.W23, U2.H8
DDR_DQ13: U1.T23, U2.H3
DDR_DQ14: U1.W22, U2.H7
DDR_DQ15: U1.Y21, U2.F8
DDR_DQM0: U1.H23, U2.D3
DDR_DQM1: U1.V22, U2.E7
DDR_DQS0_N: U1.G23, U2.B7
DDR_DQS0_P: U1.G22, U2.C7
DDR_DQS1_N: U1.U23, U2.G3
DDR_DQS1_P: U1.U22, U2.F3
DDR_ODT: R31.2, U1.L22, U2.K1
DDR_RASN: R29.2, U1.N21, U2.J3
DDR_RESETN: R27.2, U1.D20, U2.T2
DDR_WEN: R32.1, U1.M20, U2.L3
DSI_BL_CTRL: U1.AA19, U7.70
DSI_CKN: U1.A16, U5.56
DSI_CKP: U1.B16, U5.58
DSI_D0_N: U1.B15, U5.18
DSI_D0_P: U1.C15, U5.54
DSI_D1_N: U1.A17, U5.60
DSI_D1_P: U1.B17, U5.62
DSI_LCD_INT: U1.A14, U5.14
DSI_RESET: U1.D19, U5.36
DSI_TE: U1.B14, U5.16
ETH_CLK: U1.Y8, U7.48
ETH_CLK125: U1.Y6, U7.32
ETH_GTX_CLK: U1.AB2, U7.20
ETH_MDC: U1.AA6, U7.28
ETH_MDINT: U1.AC8, U7.46
ETH_MDIO: U1.AC3, U7.22
ETH_NRST: R6.1, U1.AC2, U7.18
ETH_RXD0: U1.AC7, U7.42
ETH_RXD1: U1.AB7, U7.38
ETH_RXD2: U1.AB6, U7.36
ETH_RXD3: U1.W4, U7.51
ETH_RX_CLK: U1.AA4, U7.16
ETH_RX_DV: U1.AB8, U7.44
ETH_TXD0: U1.AA2, U7.49
ETH_TXD1: U1.AA1, U7.43
ETH_TXD2: U1.Y2, U7.41
ETH_TXD3: U1.Y1, U7.39
ETH_TX_EN: U1.AB1, U7.45
GND: C1.2, C2.2, C3.2, C4.2, C5.1, C6.2, C7.2, C8.2, C9.2, C10.2, C11.2, C12.2, C13.2, C14.2, C15.2, C16.2, C17.2, C18.2, C19.2, C20.2, C21.2, C22.2, C23.2, C24.2, C25.2, C26.2, C27.2, C28.2, C29.2, C30.2, C31.2, C32.1, C33.1, C34.2, C35.2, C36.2, C37.2, C38.2, C39.2, C40.2, C41.2, C42.2, C43.2, C44.2, C45.2, C46.2, C47.2, C48.2, C49.2, C50.2, C51.2, C52.2, C53.2, C54.2, C55.2, C56.2, C57.2, C58.2, C59.2, C60.2, C61.2, C62.2, C63.2, C64.2, C65.2, C66.2, C67.2, C68.2, C69.2, C70.2, C72.2, C73.2, C74.2, C75.1, C76.1, C77.1, R1.2, R7.2, R27.1, R34.2, R35.1, R47.2, R48.2, U1.1A3, U1.1A5, U1.1A7, U1.1B2, U1.1B4, U1.1B6, U1.1B8, U1.1C1, U1.1C3, U1.1C5, U1.1C7, U1.1C9, U1.1D2, U1.1D4, U1.1D6, U1.1D8, U1.1E1, U1.1E3, U1.1E5, U1.1E7, U1.1E9, U1.1F2, U1.1F4, U1.1F6, U1.1F8, U1.1G1, U1.1G3, U1.1G5, U1.1G7, U1.1G9, U1.1H2, U1.1H4, U1.1H6, U1.1H8, U1.1J3, U1.1J5, U1.1J7, U1.A1, U1.A23, U1.AA5, U1.AA8, U1.AA12, U1.AA16, U1.AA21, U1.AB13, U1.AC1, U1.AC23, U1.C7, U1.C12, U1.C16, U1.C21, U1.D4, U1.F21, U1.H3, U1.K21, U1.L1, U1.P3, U1.P21, U1.V21, U1.W3, U2.A9, U2.B1, U2.B3, U2.B9, U2.D1, U2.D8, U2.E1, U2.E2, U2.E8, U2.F9, U2.G1, U2.G8, U2.G9, U2.J2, U2.J8, U2.M1, U2.M9, U2.P1, U2.P9, U2.T1, U2.T9, U3.A6, U3.C4, U3.D3, U3.E2, U3.E7, U3.F1, U3.G5, U3.H10, U3.J5, U3.K8, U3.N2, U3.N5, U3.P1, U3.P4, U3.P6, U4.6, U4.10, U4.15, U4.26, U4.30, U4.32, U4.41, U4.ep, U6.27, U6.29, U6.31, U6.33, U6.35, U6.61, U6.62, U6.63, U6.64, U6.65, U6.66, U6.67, U6.68, U6.69, U6.70, U8.1, U8.4, U8.5, U8.6, U8.7, U8.8, U8.11, U8.18, U8.21, U8.33, U8.35, U8.36, U8.39, U8.41, U8.42, U8.43, U8.44, U8.45, U8.46, U8.48, U8.49, U8.50, U8.51, U8.52, U8.53, U8.54, U8.55, U8.56, U8.57, U8.58, U9.4, U9.5, U9.36, U9.40, U9.41, U9.42, U9.43, U9.44, X1.2, X2.2, X2.4
HDMI_CEC: U1.Y14, U7.53
HDMI_INT: U1.W1, U7.37
HDMI_NRST: U1.Y17, U7.65
I2C1_SCL: R2.1, U1.Y18, U7.67
I2C1_SDA: R3.1, U1.Y4, U7.47
I2C4_SCL: R4.1, U1.G2, U4.4, U5.29
I2C4_SDA: R5.1, U1.H2, U4.3, U5.31
I2S2_CK: U1.D14, U5.24
I2S2_SDO: U1.E1, U5.57
I2S2_WS: U1.B10, U5.50
JTCK_SWCLK: U1.B20, U5.70
JTDI: U1.A20, U5.68
JTDO_TRACESWO: U1.A19, U5.64
JTMS_SWDIO: U1.C20, U5.34
LCD_B0: U1.K1, U5.53
LCD_B1: U1.K4, U5.45
LCD_B2: U1.AB11, U7.54
LCD_B3: U1.B5, U5.44
LCD_B4: U1.B4, U5.42
LCD_B5: U1.U2, U7.35
LCD_B6: U1.F4, U5.51
LCD_B7: U1.K3, U5.43
LCD_CLK: U1.AC14, U7.66
LCD_DE: U1.Y12, U7.50
LCD_G0: U1.AA7, U7.30
LCD_G1: U1.C10, U5.52
LCD_G2: U1.D1, U5.61
LCD_G3: U1.C3, U5.40
LCD_G4: U1.B1, U5.67
LCD_G5: U1.C1, U5.63
LCD_G6: U1.E3, U5.59
LCD_G7: U1.E2, U5.55
LCD_HSYNC: U1.T1, U7.27
LCD_R0: U1.AB4, U7.26
LCD_R1: U1.AA3, U7.14
LCD_R2: U1.D5, U5.12
LCD_R3: U1.C5, U5.10
LCD_R4: U1.C2, U5.65
LCD_R5: U1.AB5, U7.34
LCD_R6: U1.B2, U5.69
LCD_R7: U1.D3, U5.38
LCD_VSYNC: U1.H4, U5.47
MPU_VDDA_1V8_REG: C1.1, C4.1, U1.AB14, U1.C14
NJRST: U1.B19, U5.66
NRST: R46.2, U1.M3, U3.J1, U3.J2, U3.J3, U3.K5, U4.1, U5.33, U8.12
unnamed: C5.2, U1.C17, U1.C18
unnamed: C6.1, U1.AB15
unnamed: C7.1, U1.M4
unnamed: C33.2, U8.47
unnamed: C42.1, U3.C1, U3.C2
unnamed: C62.1, U4.40
unnamed: C75.2, U1.P2, X2.3
unnamed: C76.2, U1.P1, X2.1
unnamed: C77.2, U1.L2, X1.3
unnamed: L1.1, U4.7
unnamed: L2.1, U4.11
unnamed: L3.1, U4.29
unnamed: L4.1, U4.25
unnamed: R1.1, U1.K23
unnamed: R7.1, U1.AB18
unnamed: R34.1, U2.L8
unnamed: R47.1, R48.1, U8.9
unnamed: R49.1, U9.2
unnamed: R49.2, U9.3
unnamed: TP1.1, U9.25
unnamed: U8.2, U8.3
PA0_WKUP: U1.AB3, U4.43
PMIC_LDO1_1V8: C56.1, U4.23, U6.16, U6.18, U6.20, U6.22, U6.24
PMIC_LDO2_2V9: C57.1, U4.18, U6.30, U6.32, U6.34, U6.36
PMIC_LDO3_VTT_DDR: C9.1, C10.1, C11.1, C12.1, C13.1, C14.1, C15.1, C16.1, C17.1, C18.1, C19.1, C20.1, C21.1, C22.1, C58.1, R8.1, R9.1, R10.1, R11.1, R12.1, R13.1, R14.1, R15.1, R16.1, R17.1, R18.1, R19.1, R20.1, R21.1, R22.1, R23.1, R24.1, R25.1, R28.2, R29.1, R30.2, R31.1, R32.2, R33.1, U4.14
PMIC_LDO4_VDD_USB: C3.1, C59.1, U1.AA15, U1.AA17, U4.39
PMIC_LDO5_2V9: C38.1, C39.1, C40.1, C41.1, C60.1, R36.1, R37.1, R38.1, R39.1, R40.1, R41.1, R42.1, R43.1, R44.1, R45.1, U3.A9, U3.B8, U3.C6, U3.C7, U3.E6, U3.F5, U3.J10, U3.K9, U3.M4, U3.N4, U3.P3, U3.P5, U4.20, U6.51, U6.53
PMIC_LDO6_1V0: C61.1, U4.21, U6.42, U6.44, U6.46, U6.48
PMIC_VOUT1_VDD_CORE: C47.1, C63.1, C64.1, C65.1, C66.1, L1.2, U1.1A2, U1.1A4, U1.1A6, U1.1B1, U1.1B3, U1.1B5, U1.1C2, U1.1C4, U1.1C6, U1.1D1, U1.1D3, U1.1D5, U1.1D7, U1.1E2, U1.1E4, U1.1E6, U1.1F5, U1.1F7, U1.1G6, U1.1H7, U4.5
PMIC_VOUT2_VDD_DDR: C23.1, C24.1, C25.1, C26.1, C27.1, C28.1, C29.1, C30.1, C31.1, C34.1, C35.1, C48.1, C54.1, C72.1, C73.1, C74.1, L2.2, U1.1A8, U1.1B7, U1.1B9, U1.1C8, U1.1D9, U1.1E8, U1.1F9, U1.1G8, U1.1H9, U1.1J8, U2.A1, U2.A8, U2.B2, U2.C1, U2.C9, U2.D2, U2.D9, U2.E9, U2.F1, U2.G7, U2.H2, U2.H9, U2.K2, U2.K8, U2.N1, U2.N9, U2.R1, U2.R9, U4.9, U4.13
PMIC_VOUT3_VDD: C2.1, C49.1, C67.1, C68.1, C69.1, C70.1, L3.2, R2.2, R3.2, R4.2, R5.2, R6.2, R46.1, U1.1F1, U1.1F3, U1.1G2, U1.1G4, U1.1H1, U1.1H3, U1.1H5, U1.1J2, U1.1J4, U1.1J6, U1.B18, U1.R3, U1.R4, U1.T3, U4.31, U4.42, U6.15, U6.17, U6.19, U6.21, U6.23, X1.4
PMIC_VOUT4_3V3: C32.2, C50.1, L4.2, R50.1, R51.1, R52.1, R53.1, R54.1, R55.1, U4.27, U6.1, U6.3, U6.5, U6.7, U6.9, U8.10, U8.20, U8.28, U9.22, U9.23
PMIC_VREF_DDR: C8.1, C36.1, C37.1, C55.1, U1.AC20, U2.H1, U2.M8, U4.16
PMIC_WAKEUP: U1.K2, U4.2
POWER_ON: U1.R2, U4.44
SDMMC1_CK: U1.D13, U5.22
SDMMC1_CMD: U1.D12, U5.20
SDMMC1_D0: U1.D18, U5.32
SDMMC1_D1: U1.D17, U5.30
SDMMC1_D2: U1.D15, U5.26
SDMMC1_D3: U1.D16, U5.28
SDMMC2_CK: R45.2, U1.C9, U3.K1, U3.K2, U3.K3, U3.M6
SDMMC2_CMD: R44.2, U1.A10, U3.L1, U3.L2, U3.L3, U3.M5
SDMMC2_D0: R36.2, U1.C13, U3.A3
SDMMC2_D1: R37.2, U1.B12, U3.A4
SDMMC2_D2: R38.2, U1.A11, U3.A5
SDMMC2_D3: R39.2, U1.B13, U3.A1, U3.B2
SDMMC2_D4: R40.2, U1.AB10, U3.A2, U3.B3
SDMMC2_D5: R41.2, U1.A8, U3.B4, U3.C3, U3.D2, U3.E1
SDMMC2_D6: R42.2, U1.C11, U3.B5, U3.C5, U3.D4, U3.E3, U3.F2, U3.G1
SDMMC2_D7: R43.2, U1.B11, U3.A8, U3.B6, U3.B7
SDMMC3_CK: R50.2, U1.B7, U8.22
SDMMC3_CMD: R51.2, U1.A5, U8.23
SDMMC3_D0: R52.2, U1.D8, U8.24
SDMMC3_D1: R53.2, U1.D9, U8.25
SDMMC3_D2: R54.2, U1.D7, U8.26
SDMMC3_D3: R55.2, U1.D10, U8.27
SPI5_MISO: U1.AC11, U7.52
SPI5_MOSI: U1.AA14, U7.62
SPI5_NSS: U1.AA13, U7.64
SPI5_SCK: U1.AB12, U7.60
STLINK_UART4_RX: U1.B8, U5.46
STLINK_UART4_TX: U1.B9, U5.48
STUSB1600_IRQOUTn: U1.P4, U7.25
USART1_CTS: U1.G4, U5.49
USART1_RTS: U1.AB19, U7.69
USART1_RX: U1.Y16, U7.55
USART1_TX: U1.Y7, U7.40
USART3_CTS: U1.AC10, U9.16
USART3_RTS: U1.AB9, U9.17
USART3_RX: U1.AC5, U9.11
USART3_TX: U1.Y3, U9.15
USB_DM1: U1.AB17, U7.63
USB_DM2: U1.AB16, U7.59
USB_DP1: U1.AC17, U7.61
USB_DP2: U1.AC16, U7.57
U_BUTTON_1: U1.N2, U5.39
U_BUTTON_2: U1.T2, U7.29
U_LED_1: U1.L3, U5.35
U_LED_2: U1.AC4, U7.24
WIFI_IRQ: U1.A4, U8.19
WIFI_WKUP: U1.B3, U8.13
nPONKEY: U4.17, U5.27

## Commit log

2021-05-28 Placement Complete
    [STM32MP15xx_MPU.sch]
2021-05-31 PCB completed upto connectors
    [Board to Board Connectors.sch, DDR3L_RAM.sch, LB1A_R512MB_F4GB.kicad_pcb]
2021-05-31 completed power connector
    [Board to Board Connectors.sch, LB1A_R512MB_F4GB.kicad_pcb]
2021-06-01 working on connectors
    [Board to Board Connectors.sch, LB1A_R512MB_F4GB.kicad_pcb]
2021-06-02 Fully Routed
    [Board to Board Connectors.sch, LB1A_R512MB_F4GB.kicad_pcb]
2021-06-02 sch mods
    [Board to Board Connectors.sch, Connectors.sch, DDR3L_RAM.sch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]
2021-06-02 directory changes
    [Board to Board Connectors.sch, DDR3L_RAM.sch, LB1A_DCA7M4_R512MB_F4GB.kicad_pcb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]
2021-06-03 schematic verification completed
    [Board to Board Connectors.sch, STPMIC.sch, eMMC.sch]
2021-06-04 improvements on sch and pcb
    [Board to Board Connectors.sch, LB1A_DCA7M4_R512MB_F4GB.kicad_pcb, STPMIC.sch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]
2021-06-05 some more improvements
    [LB1A_DCA7M4_R512MB_F4GB.kicad_pcb]
2021-06-05 more improvements
    [Board to Board Connectors.sch, LB1A_DCA7M4_R512MB_F4GB.kicad_pcb]
2021-06-06 Improvements to PCB
    [LB1A_DCA7M4_R512MB_F4GB.kicad_pcb]
2021-06-07 pcb improvements
    [LB1A_DCA7M4_R512MB_F4GB.kicad_pcb]
2021-06-07 some more imps
    [LB1A_DCA7M4_R512MB_F4GB.kicad_pcb]
2021-06-08 more imps
    [LB1A_DCA7M4_R512MB_F4GB.kicad_pcb]
2021-06-08 more improvements on PCB
    [LB1A_DCA7M4_R512MB_F4GB.kicad_pcb]
2021-06-09 NO DRC & UNCONNECTED
    [Board to Board Connectors.sch, DDR3L_RAM.sch, LB1A_DCA7M4_R512MB_F4GB.kicad_pcb]
2021-06-09 top layer done
    [LB1A_DCA7M4_R512MB_F4GB.kicad_pcb]
2021-06-09 all layers done
    [LB1A_DCA7M4_R512MB_F4GB.kicad_pcb]
2021-06-09 board shape donne
    [LB1A_DCA7M4_R512MB_F4GB.kicad_pcb]
2021-06-09 top silkscreen completed
    [LB1A_DCA7M4_R512MB_F4GB.kicad_pcb]
2021-06-10 bottom silkscreen completed
    [LB1A_DCA7M4_R512MB_F4GB.kicad_pcb]
2021-06-10 silkscreen almost complete
    [Board to Board Connectors.sch, LB1A_DCA7M4_R512MB_F4GB.kicad_pcb]
2021-06-10 fab files added
    [LB1A_DCA7M4_R512MB_F4GB-B_Mask.gbr, LB1A_DCA7M4_R512MB_F4GB-B_Paste.gbr, LB1A_DCA7M4_R512MB_F4GB-B_SilkS.gbr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]
2021-06-11 Logic Board 1D added
    [Board to Board Connectors.sch, DDR3L_RAM.sch, LB1D_DCA7M4_R512MB_F4GB.kicad_pcb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]
2021-06-11 Pcb routing
    [LB1D_DCA7M4_R512MB_F4GB.kicad_pcb]

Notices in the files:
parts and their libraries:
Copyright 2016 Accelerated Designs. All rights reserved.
